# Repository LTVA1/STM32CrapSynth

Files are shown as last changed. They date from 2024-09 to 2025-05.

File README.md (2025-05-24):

# STM32CrapSynth

A software/hardware synth based on STM32F303RE, 4xAD9833 wave generators, one MM5437 noise generator and LTC1063 lowpass filter. Currently I seem to have burned the filter so instead there's 3rd PCM channel using the timer that was planned for filter clocking.

# Music demo

[Here's the demo](https://www.youtube.com/watch?v=L5HF_qdjZyU). I recorded each channel separately for channel oscilloscopes and then recorded them all for master sound which you can hear in the video.

# Folders

`board` - KiCAD project of the board that mounts on top of custom teacher's board like Arduino shield.
`pc_program` - small CLI program using serial library to send data to the MCU. There also lies `.fur` tracker module of the soundtrack (but remember that emulation is finished and it sounds off at times compared to real hardware)
`STM32CrapSynthFirmware` - MCU firmware written only with CMSIS register defs and simple functions. Zero HAL, LL, SPL libraries usage.

# Other programs

[STM32CrapSynth in Furnace](https://github.com/LTVA1/furnace/tree/stm32crapsynth) - A fork of Furnace chiptune tracker with added emulation of STM32CrapSynth. Also has an ability to export data (samples and stream of commands/wavetable data) into the file which is then used by `pc_program`.

# Overview and explanation

The device is capable of synthesizing 8 audio channels. Their signals are added together and the resulting sum is available on standard 3.5 mm audio jack.

There also are six phase reset timers. Two of them are MCU's internal timers and four other are four MCU's internal USARTs/UARTs which were made to generate a periodic interrupt (just like the usual timers). Each timer has 8-bit bitmask dictating which channels it affects. Each time timer fires the correspodning channel's signal phase is reset.

The device consists of three PCBs. I designed only the topmost PCB with `STM32CrapSynth` logo. Lower two PCBs were designed by my teacher.

Here is the overall image of the whole device.

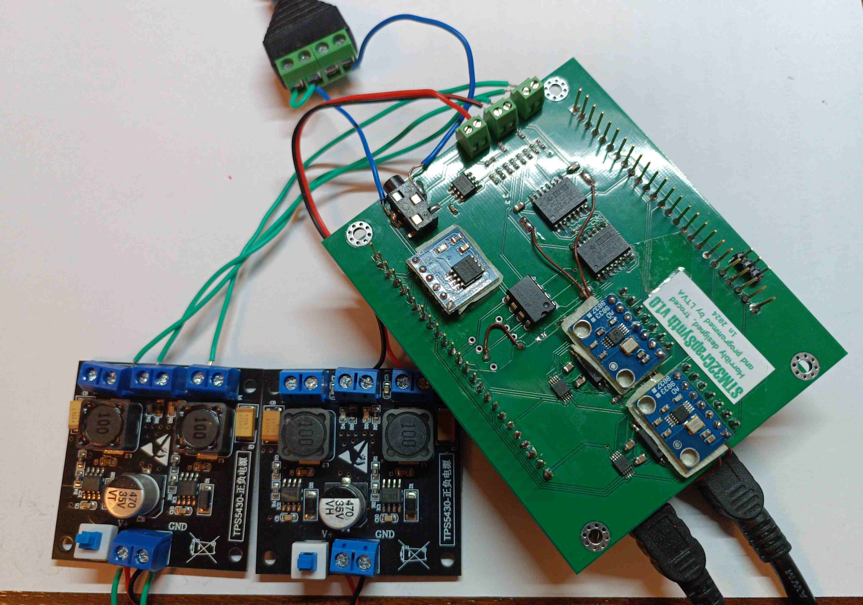
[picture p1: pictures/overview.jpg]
STM32CrapSynth


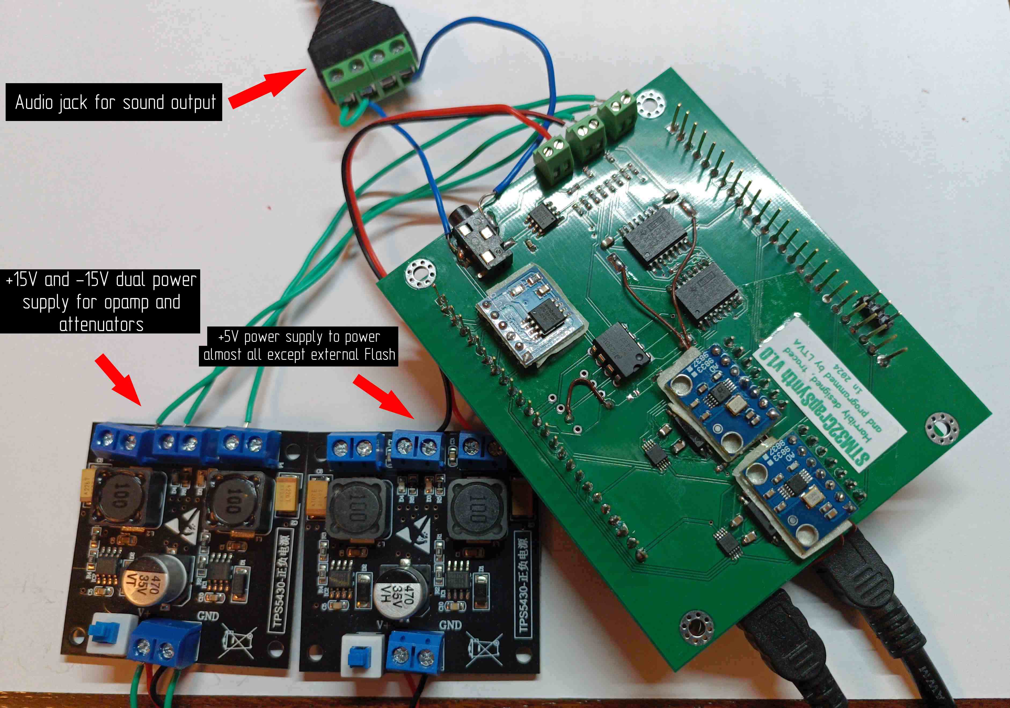
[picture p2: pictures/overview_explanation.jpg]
STM32CrapSynth explanation


## Top PCB

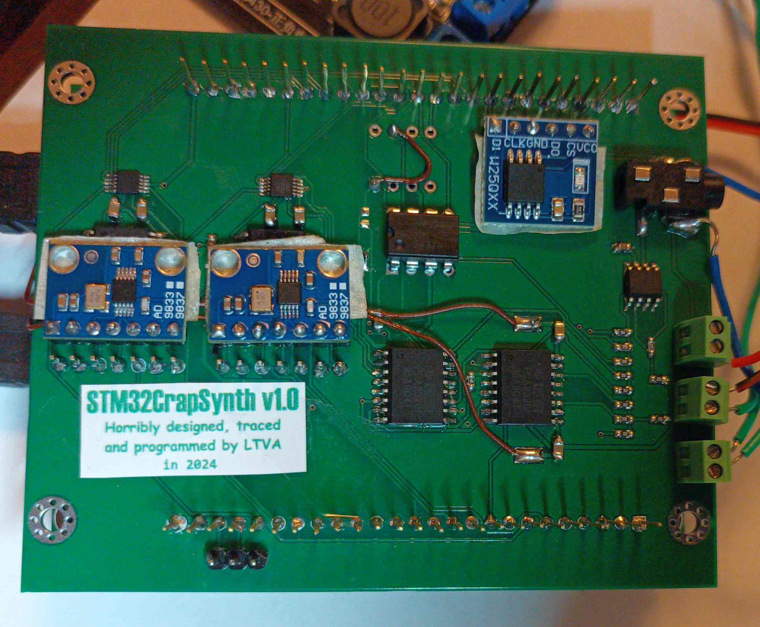
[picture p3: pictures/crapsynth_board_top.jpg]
Top PCB

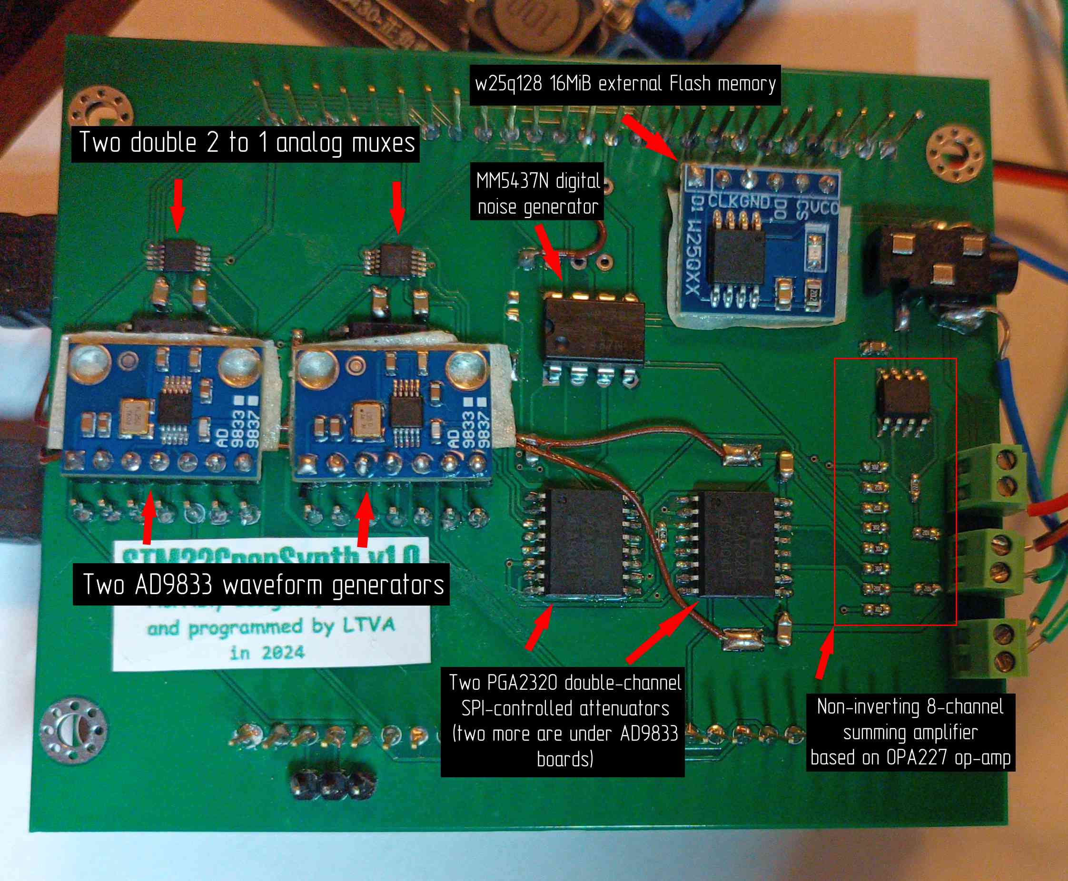
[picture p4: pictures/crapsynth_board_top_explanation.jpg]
Top PCB explanation


Muxes are used to connect either MCU timer's PWM signal or AD9833 signal to the attenuator's input. Four channels are formed, each having the ability to play sound from its own PWM timer or from its own AD9833 waveform generator.

Attenuators allow to control the channel's volume with 0.5dB step.

Noise generator can either be clocked from its own internal oscillator or from external signal (the latter is generated by dedicated MCU timer in PWM generation mode). With external clock and another control signal it's also possible to load LFSR directly from MCU, which allows to reset the noise generation at any time. That's how it is possible to "phase reset" noise channel.

The rightmost attenuator controls signals that come from brown wires. These are soldered to the outputs on MCU board that act as MCU's internal DACs outputs.

Eighth channel emerges from PWM signal that comes directly from MCU pin. Since op-amp isn't designed to handle such high frequencies, the form of the signal from this channel is distorted as you can see in demo video (triangle wave is "smoothed" on one side).

Wires were soldered to an external wires-to-audio-jack adapter because, when designing a PCB, I used wrong audio jack footprint.

External Flash memory holds a dump of commands. These commands control frequency, volume and other settings of each audio channel. They also specify the rate of their execution. Each time the timer fires (240 times a second in demo video) command execution happens until a special command is encountered. The special command stops any further execution until the timer fires next time.

## Middle PCB

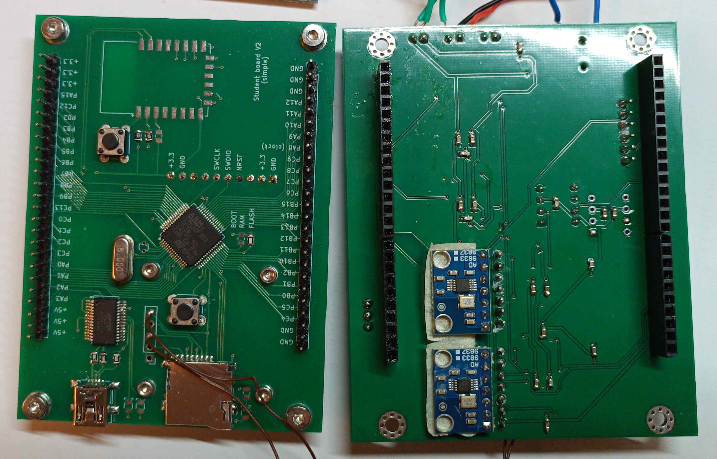
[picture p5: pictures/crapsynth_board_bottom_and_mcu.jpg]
Middle PCB

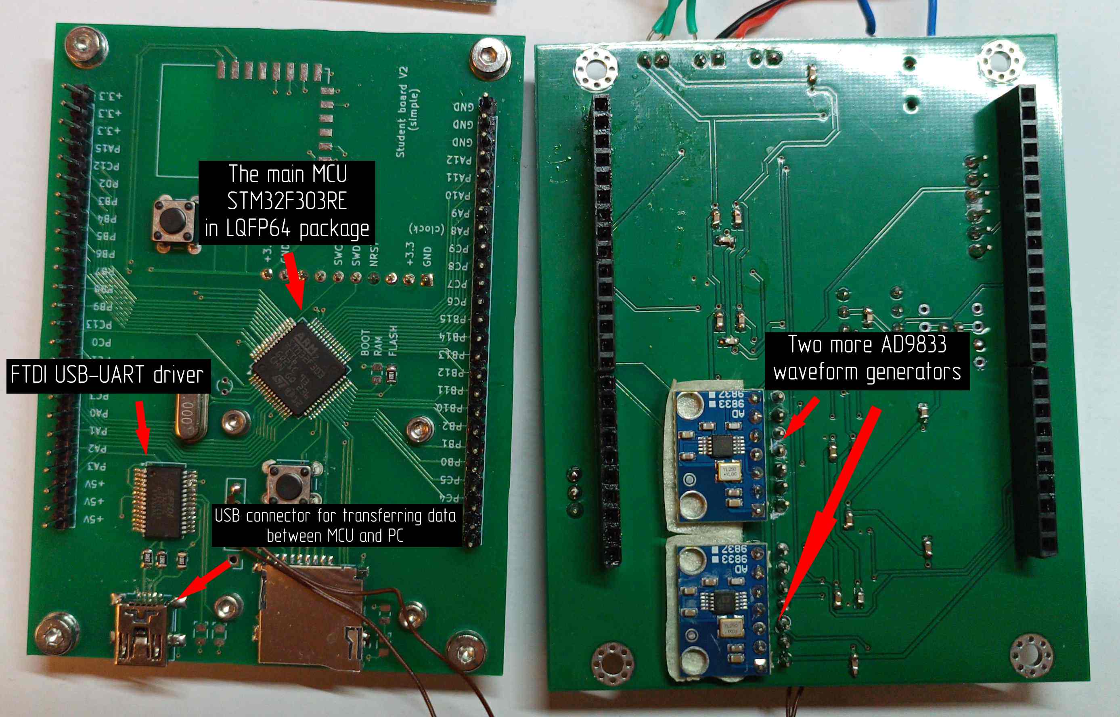
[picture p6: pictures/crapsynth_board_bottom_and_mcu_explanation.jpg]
Middle PCB explanation


On the other side on top PCB there are capacitors for power noise elimination and two more AD9833 boards.

On middle PCB you can see the main MCU that performs all the work and USB-UART bridge. The data transfer rate is 2MBaud. Also the places where DAC signal wires are soldered are visible.

## Bottom PCB

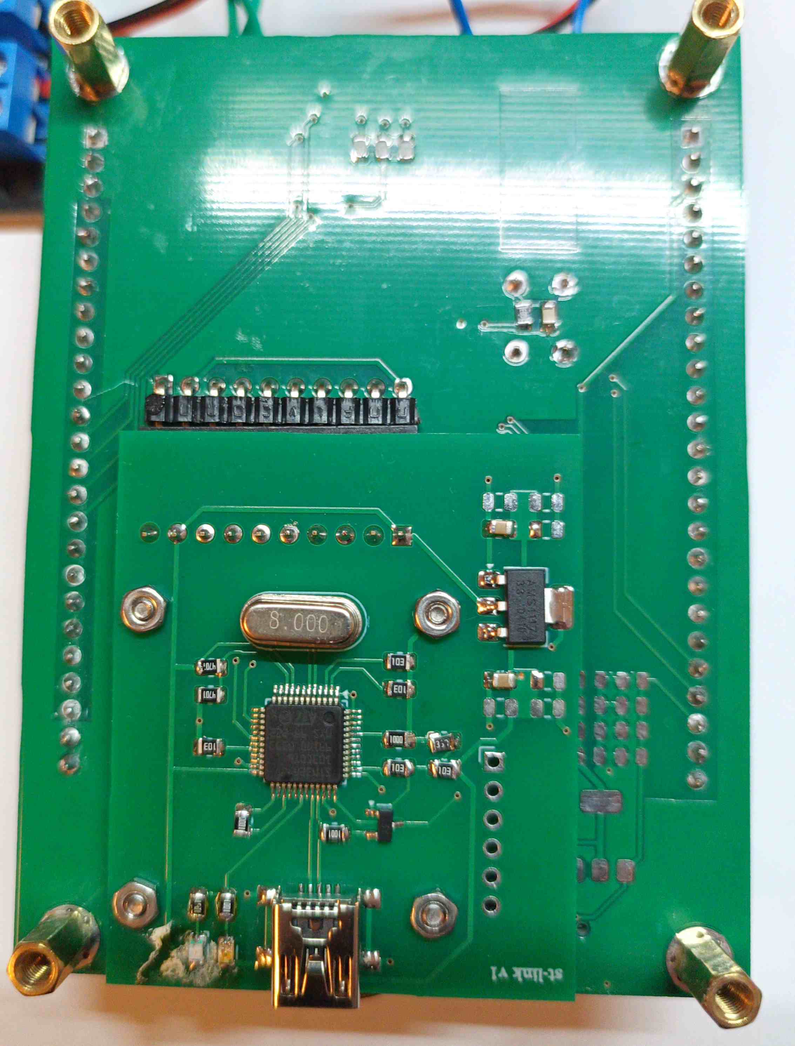
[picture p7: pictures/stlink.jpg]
Bottom PCB


Nothing special here, just a small PCB with custom STLink debugger design. A connector between bottom and middle PCB is visible on top. The USB connector provides power to STLink.

Also this board has 3.3V power regulator that supplies main MCU and external Flash memory.

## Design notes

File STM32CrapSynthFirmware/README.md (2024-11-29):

Startup file and linker script were modified. The correct size of CCMRAM (16KiB instead of 8KiB) was specified. CCMRAM sections for code and data were added in linker script. Startup file was modified to include CCMRAM copy of vector table, and copying routine was added to copy the part of the firmware from Flash to CCMRAM.

The main program copies interrupt vector table to CCMRAM and writes its new address to VTOR register of SCB.

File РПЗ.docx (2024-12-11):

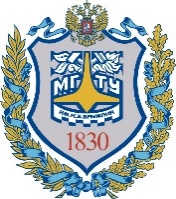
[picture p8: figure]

| Министерство науки и высшего образования Российской Федерации Федеральное государственное бюджетное образовательное учреждение высшего образования «Московский государственный технический университет имени Н.Э. Баумана (национальный исследовательский университет)» (МГТУ им. Н.Э. Баумана)

ФАКУЛЬТЕТ | «Радиоэлектроника и лазерная техника (РЛ)»
КАФЕДРА | «Технологии приборостроения (РЛ6)»

РАСЧЁТНО-ПОЯСНИТЕЛЬНАЯ ЗАПИСКА

К КУРСОВОЙ РАБОТЕ

НА ТЕМУ:

«Устройство программно-аппаратного синтеза звука»

ПО КУРСУ

«Цифровая электроника и микропроцессорная техника»

Студент | РЛ6-71 | | | | Г.С. Сарайкин
| (группа) | | (подпись, дата) | | (И.О. Фамилия)
Руководитель курсового проекта | | | | | Д. А. Семеренко
| | | (подпись, дата) | | (И.О. Фамилия)

2024 г.

# Введение

Аппаратный синтез звука с программным управлением может применяться в устройствах тестирования звуковой аппаратуры и синтезаторах.

Формирование сигнала возможно с помощью специализированных микросхем или использования аппаратных возможностей цифровых вычислительных устройств.

В курсовой работе реализован синтез методами DDS и ШИМ, также реализован сэмплерный синтез. Синтез реализован аппаратно с программным управлением, что позволяет достичь управления тембром и громкостью каналов во времени.

Цель работы — разработать устройство, генерирующее звук при помощи сэмплерного синтеза, а также методами DDS и ШИМ.

Назначение устройства — генерация восьми сигналов их суммирование и передача через звуковой разъём на устройство воспроизведения звука.

# 1. Обзор существующих решений

Стандартным методом формирования звуковых сигналов является использование ЦАПов с разнообразными устройствами, формирующими входящий в них поток цифровых данных.

Метод синтеза DDS (англ. Direct Digital Synthesis, прямой цифровой синтез звука) заключается в формировании сигнала при помощи преобразования цифрового значения фазы в цифровые значения мгновенной амплитуды по определённому закону. Фаза задаётся при помощи регистра аккумулятора фазы, к значению в котором с каждым тактом системной частоты прибавляется значение регистра, хранящего текущую настройку частоты. Благодаря тому, что регистр фазы переполняется (при сложении разряд переполнения отбрасывается), достигается циклическое нарастание значения фазы в регистре. Это позволяет синтезировать повторяющуюся во времени волну, установив закон соответствия выходной амплитуды текущему значению фазы [2]. Обобщённая функциональная схема DDS-генератора представлена на Рисунке 1.

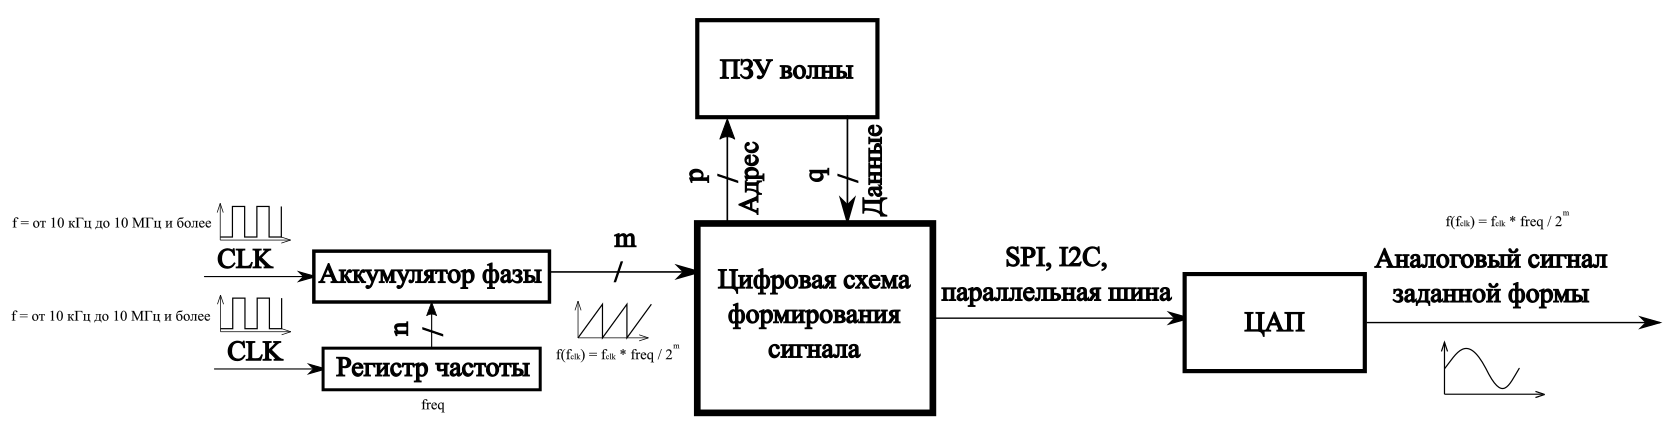
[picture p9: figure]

Рисунок 1 — Обобщённая функциональная схема DDS-генератора

Синтез ШИМ-сигнала при помощи таймера микроконтроллера заключается в создании выходного ШИМ-сигнала на основании текущих значений коэффициента заполнения и периода импульсов. Эти значения хранятся в регистрах таймера, реализованного внутри микроконтроллера. При изменении коэффициента заполнения меняется спектральный состав выходного сигнала. При частоте импульсов, попадающей в диапазон слышимости человека, изменение коэффициента заполнения воспринимается как изменение тембра звучания волны. Детальное объяснение применения ШИМ-сигнала для синтеза используемых в электронной музыке звуков см. в [3]. Обобщённая функциональная схема ШИМ-генератора представлена на Рисунке 2.

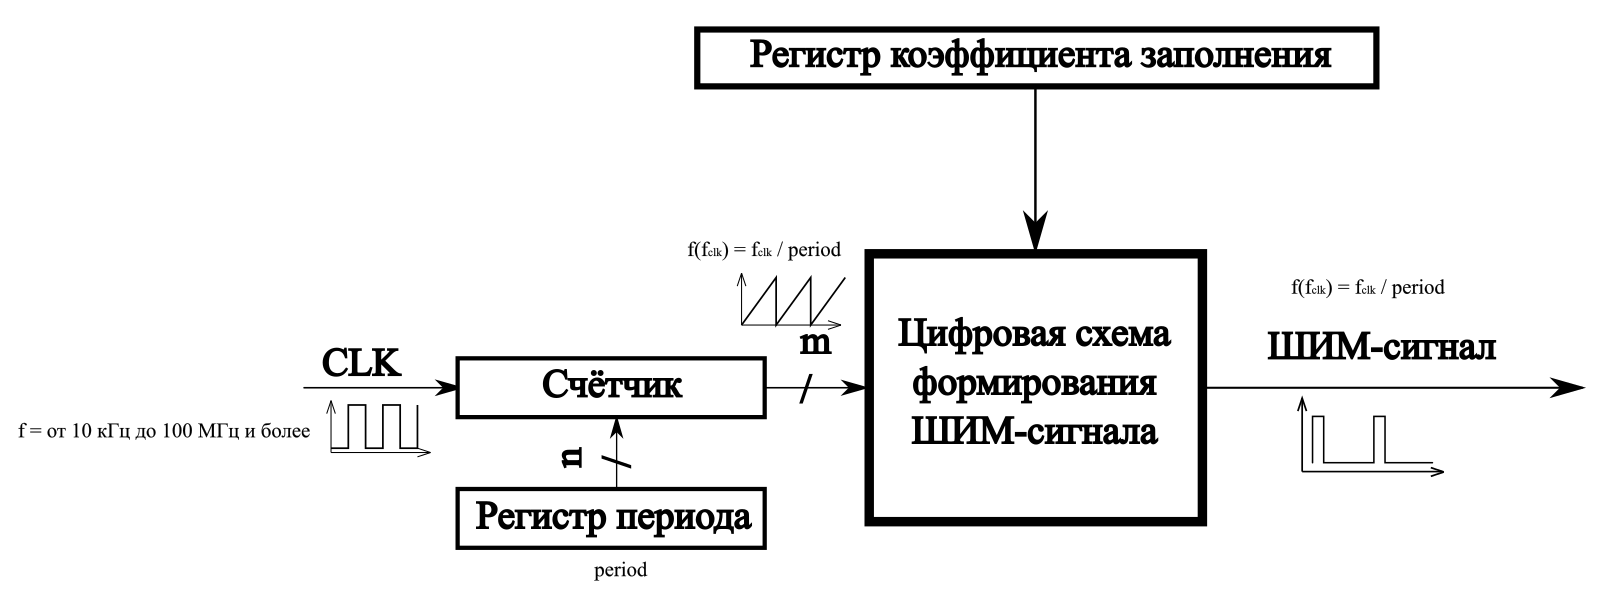
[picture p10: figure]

Рисунок 2 — Обобщённая функциональная схема синтезатора ШИМ-сигнала

Методы DDS и ШИМ схожи между собой, поскольку оба этих метода позволяют формировать повторяющийся во времени сигнал (один период волны). Метод ШИМ позволяет управлять тембром путём изменения коэффициента заполнения импульсов, а метод DDS — путём изменения типа синтезируемой волны (смены закона соответствия выходной амплитуды сигнала текущему значению фазы). Метод DDS в теории более универсален, поскольку позволяет выбирать между несколькими формами сигналов, в то время как метод ШИМ ограничен прямоугольной волной с изменяемым коэффициентом заполнения, что накладывает ограничения на тембры, которые возможно формировать при помощи этого метода. В некоторых устройствах можно встретить реализацию комбинации этих методов внутри одного функционального узла, т.е. доступна как генерация прямоугольных волн с изменяемым коэффициентом заполнения, так и других типов волн (треугольная и пилообразная) [6].

Сэмплерный синтез заключается в проигрывании подаваемых на вход ЦАПа наборов отсчётов оцифрованного звука, называемых сэмплами. Сэмпл можно воспроизвести целиком однократно, воспроизводить циклично целиком или проиграть часть сэмпла однократно, а оставшуюся часть циклично. Этот метод синтеза позволяет воспроизводить практически неограниченный набор звуков. Ограничениями метода являются глубина и частота дискретизации сэмплов и количество памяти, в которую записаны эти сэмплы [4].

Таблично-волновой синтез аналогичен сэмплерному синтезу за исключением того, что вместо сэмплов используются короткие наборы отсчётов (волновые таблицы), циклично воспроизводящиеся во времени. В результате получается волна, тембр которой можно менять, меняя эти наборы отсчётов [5].

Обобщённая функциональная схема сэмплерного/таблично-волнового синтезатора представлена на Рисунке 3.

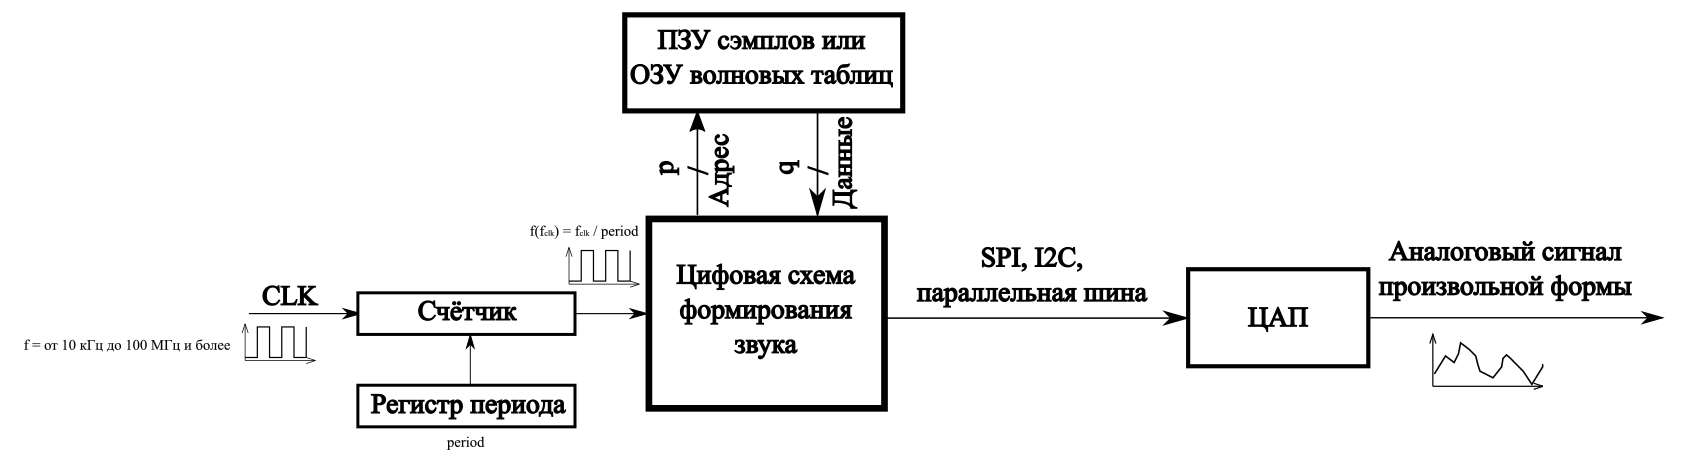
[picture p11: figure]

Рисунок 3 — Обобщённая функциональная схема сэмплерного/таблично-волнового синтезатора

Аналогами устройства являются звуковые чипы — специализированные микросхемы, основным назначением которых является генерация одного или нескольких сигналов, сумма которых в виде аналогового сигнала или потока цифровых данных подаётся на выход микросхемы.

Примером звукового чипа является MOS Technology SID [6]. Это микросхема трёхканального звукогенератора. Каждый канал может воспроизводить треугольную волну, шум, пилообразную волну или прямоугольную волну с настраиваемым коэффициентом заполнения. Частота волны каждого канала настраивается независимо. Для каждого канала реализована аппаратная ADSR-огибающая громкости. Сигнал каждого из каналов можно либо подключать напрямую на выход микросхемы, либо пропускать через аналоговый многорежимный фильтр с цифровым управлением. У фильтра настраиваются частота среза, добротность и режим (фильтр нижних частот, фильтр верхних частот, полосовой фильтр или любая комбинация этих режимов).

# 2. Алгоритм работы

Устройство генерирует звук с помощью внешних DDS-генераторов (синус, треугольная и квадратная волны), внутренних таймеров микроконтроллера (ШИМ, прямоугольная волна с изменяемым коэффициентом заполнения), внешнего генератора шума (псевдо-белый шум), внутренних таймеров микроконтроллера в связке с внутренними ЦАПами (волновые таблицы и сэмплы). Эти сигналы проходят через программно управляемые аттенюаторы, что позволяет задавать уровень и огибающую громкости. Сигнал одного из DDS-генераторов проходит через цифровой фильтр нижних частот пятого порядка с АЧХ Баттерворта. Частота среза фильтра зависит от частоты тактирования фильтра [7]. Ещё один ШИМ-сигнал приходит напрямую в аналоговый сумматор.

В устройстве также реализовано шесть таймеров сброса фазы. Для каждого таймера настраиваются каналы, на которые он воздействует. При каждом срабатывании таймера сбрасывается фаза всех каналов, на которые он воздействует. Описание принципа сброса фазы см. в описании соответствующих команд в Приложении А.

Функциональная схема устройства приведена на Рисунке 4.

Принципиальная электрическая схема устройства приведена в Приложении Г.

Рисунок 4 — Функциональная схема устройства

Сэмплы необходимо хранить во внутренней флэш-памяти микроконтроллера и во внутренней оперативной памяти. Волновые таблицы и последовательность команд, изменяющих параметры синтеза, необходимо хранить во внешней флэш-памяти, подключённой по SPI. Устройство использует 496 КиБ внутренней флэш-памяти микроконтроллера и 52 КиБ ОЗУ микроконтроллера для хранения сэмплов.

Программное управление осуществляется через интерфейс UART. ПК посылает команды, которые исполняются устройством. Команды позволяют запускать или останавливать исполнение потока команд, записанного во внешнюю флэш-память, а также позволяют загружать новые данные с ПК во внешнюю флэш-память, внутреннюю флэш-память и ОЗУ микроконтроллера.

Команды, хранящиеся во внешней флэш-памяти, состоят из байта, кодирующего тип команды и номер канала, параметры которого она меняет. После команды может следовать один или несколько байтов параметров команды, которые определяют новое значение параметра канала, к которому относится команда. Формат команд описан в Приложении А.

Обмен данными между микроконтроллером и внешней флэш-памятью осуществляется при помощи контроллера DMA по SPI.

Исполнение команд происходит через фиксированные интервалы времени, отсчитываемые одним из таймеров микроконтроллера (далее — таймер исполнения команд). Каждый раз, когда происходит срабатывание таймера, в обработчике прерывания таймера выставляется флаг запроса исполнения команд. В основном потоке программы проверяется установка флага, и при его установке начинается исполнение команд. По окончании исполнения команд флаг сбрасывается.

Данные с ПК передаются при помощи специально разработанной программы с интерфейсом командной строки. Программа читает файл, название которого задаётся пользователем. В файле записана последовательность команд и сэмплы. Программа формирует команды с пакетами данных, передаваемые микроконтроллеру, и ожидает подтверждения приёма от микроконтроллера. Пакеты данных содержат информацию, прочитанную программой из файла. Формат пакетов, которыми обмениваются микроконтроллер и программа, приведён в Приложении Б. В консоль выводится информация о прогрессе передачи данных, обновляемая с каждой передачей пакета. После передачи всех данных пользователю предоставляется возможность запускать или останавливать исполнение потока команд.

Формат файла приведён в Приложении В.

# Заключение

В курсовой работе разработано устройство многоканальной генерации звука, реализовано управление устройством с ПК.

Продемонстрирована возможность выполнения потока команд, записанного во внешнюю флэш-память, а также использование DDS-генераторов и внутренних таймеров микроконтроллера для генерации сигналов на частотах от 10 Гц до 20 кГц. Устройство способно выполнять обновление параметров каналов с частотой до 240 Гц.

Устройство можно улучшить путём увеличения числа каналов и/или увеличения возможностей каналов. Вместо использования отдельных микросхем DDS-генераторов и генератора шума возможна реализация синтеза на ПЛИС. При подключении к ПЛИС внешней оперативной памяти станет возможно увеличение общего объёма памяти сэмплов, а также реализация самих каналов сэмплов на ПЛИС, что потребует использования внешних ЦАПов.

Исходный код программы для микроконтроллера доступен по ссылке [8]. Исходный код программы для ПК доступен по ссылке [9].

# Приложение А. Формат команд управления параметрами синтеза

Команды делятся на обычные и служебные. Обычные команды предназначены для изменения одного из параметров синтеза определённого канала, в то время как служебные команды контролируют порядок выполнения обычных команд. Общий формат команд представлен в Таблице А1.

Таблица А1

Байт 1 | Байты 2, 3, …
Байт команды | Параметр(-ы) (размер и наличие зависят от команды)

Формат обычных команд для каналов DDS/ШИМ представлен в Таблице А2. Формат обычных команд для канала шума представлен в Таблице А3. Формат команд для каналов сэмплов представлен в Таблице А4. Формат команд для каналов таймеров сброса фазы представлен в Таблице А5. Формат служебных команд представлен в Таблице А6.

Нумерация каналов начинается с нуля. Соответственно, для DDS/ШИМ каналов номер лежит в диапазоне от 0 до 3. Для каналов ЦАПов номер лежит в диапазоне от 0 до 2, где последний канал соответствует ЦАПу, реализованному при помощи ШИМ. Для каналов таймеров сброса фазы номер лежит в диапазоне от 0 до 5.

Каждый байт параметра представляется в виде двух латинских букв, написанных слитно, например, aa. Если параметр имеет размер более одного байта, он представляется в виде нескольких групп из двух латинских букв, например, aa aa. В таком случае сначала следует младший байт, а потом старший. Такой порядок байтов сохраняется и при большем размере параметра (3 и более байтов), в этом случае сначала идёт самый младший байт, потом следующий за ним, и так далее до самого старшего байта. В случае наличия нескольких параметров каждый параметр обозначается своими буквами. Например, aa aa bb значит, что сначала следует один параметр размером два байта, а после него следует второй параметр размером один байт.

Если количество битов параметра не кратно восьми (например, написано, что значение параметра занимает 14 бит, а сам параметр занимает два байта, т.е. 16 бит), то используются только младшие биты (в описанном случае используются 14 младших бит, два старших бита не используются и игнорируются при исполнении команды).

Если указано использование конкретных значений параметра, например, описаны значения от 0 до 5, то значения параметра, не попадающие в диапазон, не приводят к какому-либо изменению параметров синтеза. При этом выполнение команд не прерывается.

Если информации о параметре не указано, то параметр отсутствует, и команда занимает один байт.

Таблица А2

Описание команды | Значение байта команды, n — номер канала | Формат параметра(-ов) | Описание функций команды и параметра(-ов)
Установка громкости | 8×n | vv | vv — громкость канала. Если vv = 0, то громкость равна нулю, иначе громкость равна -97+0,5× (vv)дБ для типов волн 1 и 2 и -88+0,5× (vv)дБ для типов волн 3 и 4.
Установка типа волны | 8×n+1 | ww | ww — тип волны, синтезируемой каналом: 0 — нет сигнала; 1 — синус; 2 — треугольная волна; 3 — квадратная волна; 4 — квадратная волна с удвоенной частотой; 5 — прямоугольная волна с настраиваемым коэффициентом заполнения.
Частота для типов волн от 1 до 4 | 8×n+2 | ff ff ff ff | ff ff ff ff — 28-битное целое положительное число, задающее частоту сигнала по формуле f_(signal) =((ff ff ff ff)×25 МГц)/(2^28) . Максимальная частота составляет 12,5 МГц для типа волны 1 и 2 МГц для остальных типов.
Сброс фазы | 8×n+3 | | При исполнении этой команды фаза волны принудительно устанавливается равной нулю вне зависимости от типа волны и текущих значений частоты и фазы.
Частота для типа волны 5 | 8×n+4 | pp aa aa | pp — предделитель частоты, aa aa — делитель частоты. Частота сигнала вычисляется по формуле f_(signal) =(72 МГц)/(((aa aa) + 1)×((pp)+1)) .
Коэффициент заполнения для типа волны 5 | 8×n+5 | dd dd | dd dd — коэффициент заполнения. Реальный коэффициент заполнения вычисляется по формуле d_(real) =((dd dd))/((aa aa))×100% , где aa aa — текущее значение делителя частоты (см. описание предыдущей команды).
Включение изменения громкости по пересечению нуля | 8×n+6 | | Команда применяется к паре каналов (пары каналов: 0 и 1, 2 и 3) одновременно при исполнении команды для одного из этих каналов
Выключение изменения громкости по пересечению нуля | 8×n+7 | | Команда применяется к паре каналов (пары каналов: 0 и 1, 2 и 3) одновременно при исполнении команды для одного из этих каналов

Таблица А3

Описание команды | Значение байта команды | Формат параметра(-ов) | Описание функций команды и параметра(-ов)
Установка громкости | 32 | vv | vv — громкость канала. Если vv = 0, то громкость равна нулю, иначе громкость равна -88+0,5× (vv) дБ.
Тактирование генератора шума от внутреннего источника | 33 | | Частота тактирования составляет примерно 100 кГц
Тактирование генератора шума от внешнего источника | 34 | | Частота тактирования настраивается командой «Частота внешнего тактирования»
Включение изменения громкости по пересечению нуля | 35
Выключение изменения громкости по пересечению нуля | 36
Частота внешнего тактирования | 37 | pp aa aa | pp — предделитель частоты, aa aa — делитель частоты. Частота тактирования генератора шума вычисляется по формуле f_(clk) =(72 МГц)/(((aa aa) + 1)×((pp)+1)) . Частота тактирования не должна превышать 300 кГц.
Сброс фазы | 38 | | Команда загружает в РСЛОС генератора шума значение, заданное командой «Установка начального состояния РСЛОС»
Установка начального состояния РСЛОС | 39 | ll ll ll | ll ll ll — 23-битное значение состояния РСЛОС

Таблица А4

Описание команды | Значение байта команды, n — номер канала | Формат параметра(-ов) | Описание функций команды и параметра(-ов)
Установить громкость канала | 40+16×n | vv | vv — громкость канала. Если vv = 0, то громкость равна нулю, иначе громкость равна -88+0,5× ( vv ) дБ для n∈{0,1} и -12+10×log_10 ((256+3×(vv))/256) дБ для n=2.
Начать воспроизведение сэмпла | 41+16×n | | Сэмпл начинает воспроизводиться с заданными ранее начальными параметрами (см. следующие команды)
Начать воспроизведение сэмпла с зацикливанием | 42+16×n | | Сэмпл начинает воспроизводиться с заданными ранее начальными параметрами (см. следующие команды). При этом учитывается настройка точки зацикливания
Начать воспроизведение волновой таблицы | 43+16×n | | Волновая таблица начинает воспроизводиться с заданными ранее начальными параметрами (см. следующие команды)
Остановить воспроизведение волновой таблицы или сэмпла | 44+16×n
Задать стартовый адрес сэмпла во внутренней флэш-памяти | 45+16×n | ss ss ss | ss ss ss — сдвиг начала сэмпла относительно начала области внутренней флэш-памяти, отведённой под сэмплы
Задать стартовый адрес сэмпла в ОЗУ | 46+16×n | ss ss | ss ss — сдвиг начала сэмпла относительно начала области ОЗУ, отведённой под сэмплы
Сброс фазы волновой таблицы или сэмпла | 47+16×n | | В случае волновой таблицы фаза волны, представленной в ней, сбрасывается в ноль. В случае сэмпла воспроизведение сэмпла начинается заново с первого отсчёта этого сэмпла.
Частота воспроизведения сэмпла или волновой таблицы | 48+16×n | pp aa aa | pp — предделитель частоты, aa aa — делитель частоты. Частота тактирования воспроизведения сэмпла вычисляется по формуле f_(sample) =(72 МГц)/(((aa aa) + 1)×((pp)+1)) . Частота воспроизведения волновой таблицы в 256 раз меньше f_(sample) .
Включение изменения громкости по пересечению нуля | 49+16×n | | Команда применяется к паре каналов (пара каналов: 0 и 1) одновременно при исполнении команды для одного из этих каналов
Выключение изменения громкости по пересечению нуля | 50+16×n | | Команда применяется к паре каналов (пара каналов: 0 и 1) одновременно при исполнении команды для одного из этих каналов
Задать адрес точки зацикливания сэмпла во внутренней флэш-памяти | 51+16×n | ll ll ll | ll ll ll — сдвиг точки зацикливания относительно стартового адреса сэмпла во флэш-памяти
Задать адрес точки зацикливания сэмпла в ОЗУ | 52+16×n | ll ll | ll ll — сдвиг точки зацикливания относительно стартового адреса сэмпла в ОЗУ
Задать длину сэмпла во внутренней флэш-памяти | 53+16×n | ll ll ll | ll ll ll — длина сэмпла во флэш-памяти
Задать длину сэмпла в ОЗУ | 54+16×n | ll ll | ll ll — длина сэмпла в ОЗУ

Задать тип волны

55+16×n

ww

ww — тип волны, синтезируемой каналом:

0 — нет сигнала;

1 — волновая таблица или сэмпл;

2 — треугольная волна;

3 — сумма волновой таблицы или сэмпла и треугольной волны;

4 — шум;

5 — сумма волновой таблицы или сэмпла и шума;

6 — прямоугольная волна с настраиваемым коэффициентом заполнения (при помощи формирования волновой таблицы);

7 — пилообразная волна (при помощи формирования волновой таблицы). При использовании типов волн 3 и 5 возможно переполнение итогового значения, в этом случае отсчёты итогового сигнала вычисляются по модулю 4096. Для n=2 синтезируются только волны 0, 1, 6, 7. Остальные каналы могут синтезировать все волны.
Коэффициент заполнения для типа волны 6 | 56+16×n | dd | dd — коэффициент заполнения. Реальный коэффициент заполнения вычисляется по формуле d_(real) =((dd))/256×100%.
Данные волновой таблицы | 57+16×n | [dd] | [dd] — массив из 256 байтов, задающий волновую таблицу. Каждый байт соответствует одному отсчёту волновой таблицы. Массив данных в неизменном виде используется в качестве волновой таблицы.
Амплитуда треугольной волны или шума | 58+16×n | aa | aa — амплитуда треугольной волны или шума, находится в диапазоне от 0 до 11. Амплитуда вычисляется по формуле A_(wave) =(2^((aa+1)))/4096×A_(max) , где A_(max) — максимально возможная для ЦАПа амплитуда выходного сигнала.

Примечание: частота треугольной волны вычисляется по формуле f_(triangle) =(2^((12-(aa+1))))/8192×f_(sample) , где f_(sample) — частота воспроизведения сэмпла или волновой таблицы, aa — текущее значение амплитуды (см. описание команды «Амплитуда треугольной волны или шума»).

Таблица А5

Описание команды | Значение байта команды, n — номер канала | Формат параметра(-ов) | Описание функций команды и параметра(-ов)
Установить битовую маску таймера | 136+8×n | bb | bb — битовая маска воздействия таймеров на каналы. Если бит равен единице, то таймер воздействует на канал и сбрасывает его фазу. Если бит равен нулю, то воздействия на канал не происходит. Соответствие битов и каналов (от младшего бита к старшим): биты 0-3 — каналы 0-3 DDS/ШИМ, бит 4 — канал шума, биты 5-7 — каналы 0-2 ЦАПов.
Частота срабатывания таймера 1 | 137+8×n | pp aa aa | pp — предделитель частоты, aa aa — делитель частоты. Частота срабатывания таймера вычисляется по формуле f_(timer) =(72 МГц)/(((aa aa) + 1)×((pp)+1)) . Работает только для n=0 .
Сброс фазы таймера | 138+8×n
Включить таймер | 139+8×n
Выключить таймер | 140+8×n
Частота срабатывания таймера 2 | 141+8×n | aa aa aa | aa aa aa — делитель частоты. Частота срабатывания таймера вычисляется по формуле f_(timer) =(72 МГц)/(((aa aa aa) + 1)) . Работает только для n=1 .
Частота срабатывания таймеров 3-6 | 142+8×n | ff ff | ff ff — делитель частоты. Значение делителя не должно превышать 65527. Частота срабатывания таймера вычисляется по формуле f_(timer) =(7,2 МГц)/((ff ff ff)) для n=2 и по формуле f_(timer) =(3,6 МГц)/((ff ff ff)) для n∈{3,4,5} . Работает только для n∈{2,3, 4,5} .

Таблица А6

Описание команды | Значение байта команды | Формат параметра(-ов) | Описание функций команды и параметра(-ов)
Ждать до следующего срабатывания таймера исполнения команд | 251
Установить частоту срабатывания таймера исполнения команд | 252 | aa aa aa aa | aa aa aa aa — делитель частоты. Частота срабатывания таймера вычисляется по формуле f_(tick) =(72 МГц)/((aa aa aa aa) + 1) .
Установить точку зацикливания | 253 | aa aa aa aa | aa aa aa aa — абсолютный адрес во внешней флэш-памяти. При исполнении команды прерывается исполнение потока команд. Микроконтроллер переходит на этот адрес и начинает читать и исполнять команды.
Остановить исполнение команд | 254
Ничего не делать | 255 | | Микроконтроллер не изменяет никаких параметров синтеза и переходит к исполнению следующей команды.

# Приложение Б. Формат пакетов обмена данными между микроконтроллером и ПК

Пакеты делятся на пакеты данных, передаваемые от ПК микроконтроллеру, и ответные пакеты, отправляемые микроконтроллером ПК.

Общий формат команд, передаваемых от ПК микроконтроллеру, представлен в Таблице Б1. Нумерация байтов начинается с единицы.

Числа, представление которых занимает несколько байтов, записаны младшим байтом вперёд, если не указано иное.

Таблица Б1

Номер байта (или диапазон для группы байтов) | Размер (указывается для группы байтов) | Описание байта (группы байтов)
1 | | Байт синхронизации, всегда равен 6916
2-3 | 2 | Размер пакета минус один байт. Сначала идёт старший байт, а потом младший.
4 | | Код команды
4-(4 + размер - 8) | размер - 8 | Данные. Эта часть пакета может отсутствовать.
(4 + размер - 7) | | Проверочный байт, вычисляется как исключающее ИЛИ от всех предыдущих байтов

Общий формат команд, передаваемых от микроконтроллера ПК, представлен в Таблице Б2. Нумерация байтов начинается с единицы.

Таблица Б2

Номер байта (или диапазон для группы байтов) | Размер (указывается для группы байтов) | Описание байта (группы байтов)
1 | | Байт синхронизации, всегда равен 6916
2 | | Код пакета
3 | 45 | Данные пакета
48 | | Проверочный байт, вычисляется как исключающее ИЛИ от всех предыдущих байтов

Коды команд, передаваемых от ПК микроконтроллеру, представлены в Таблице Б3.

Таблица Б3

Код команды | Описание команды
0 | Загрузить данные пакета во внутреннюю флэш-память
1 | Загрузить данные пакета во внутреннее ОЗУ
2 | Загрузить данные пакета во внешнюю флэш-память
3 | Начать исполнение потока команд
4 | Закончить исполнение потока команд

Коды пакетов, передаваемых от микроконтроллера ПК, представлены в Таблице Б4.

Таблица Б4

Код пакета | Описание пакета
0 | Начальный пакет: версия программы микроконтроллера, количество свободной памяти, размер внешней флэш-памяти и т.д.
1 | Пакет с информацией о завершении записи данных во внутреннюю флэш-память
2 | Пакет с информацией о завершении записи данных во внутреннее ОЗУ
3 | Пакет с информацией о завершении записи данных во внешнюю флэш-память
4 | Пакет с сообщением о неправильном значении проверочного байта
5 | Пакет с сообщением о неизвестном коде принятой команды

Команды, передаваемые от ПК микроконтроллеру и имеющие коды от 0 до 2, имеют общий формат данных. Формат представлен в Таблице Б5.

Таблица Б5

Номер байта (или диапазон для группы байтов) | Размер (указывается для группы байтов) | Описание байта (группы байтов)
1-4 | 4 | 32-битное положительное число, начальное смещение данных пакета относительно начала области памяти, в которую он записывается.
5-конец | (размер блока - 4) | Данные, которые записываются в соответствующую память

Команды, передаваемые от ПК микроконтроллеру и имеющие коды от 3 до 4, не имеют блока данных. Таким образом, их общая длина составляет 5 байтов, а в поле размера указывается число 4.

Формат данных пакета, передаваемого от микроконтроллера ПК и имеющего код пакета 0, представлен в Таблице Б6.

Таблица Б6

Номер байта (или диапазон для группы байтов) | Размер (указывается для группы байтов) | Описание байта (группы байтов)
1-4 | 4 | 32-битное положительное число, размер программы микроконтроллера, занимаемый ею во внутренней флэш-памяти
5-8 | 4 | 32-битное положительное число, начальное смещение области памяти, отведённой под сэмплы, во внутренней флэш-памяти микроконтроллера
9-12 | 4 | 32-битное положительное число, начальное смещение области памяти, отведённой под сэмплы, в ОЗУ микроконтроллера
13-16 | 4 | 32-битное положительное число, максимальная поддерживаемая программой микроконтроллера версия файла (см. Приложение В)
17-20 | 4 | 32-битное положительное число, версия программы микроконтроллера
21-24 | 4 | 32-битное положительное число, размер (в байтах) внешней флэш-памяти
25-32 | 8 | 64-битное положительное число, UID внешней флэш-памяти
33 | 1 | Идентификатор производителя внешней флэш-памяти
34-45 | 12 | Байты не используются. Игнорировать при чтении.

Команды, передаваемые от микроконтроллера ПК и имеющие коды от 1 до 3, имеют общий формат данных. Формат представлен в Таблице Б5.

Таблица Б6

Номер байта (или диапазон для группы байтов) | Размер (указывается для группы байтов) | Описание байта (группы байтов)
1 | | Проверочный байт пришедшего от ПК пакета данных
2-5 | 4 | 32-битное положительное число, начальное смещение данных в пришедшем от ПК пакете данных
6-7 | 2 | 16-битное положительное число, длина блока данных в пришедшем от ПК пакете данных
8-45 | 38 | Байты не используются. Игнорировать при чтении.

Пакеты, передаваемые от микроконтроллера ПК и имеющие коды от 4 до 5, не содержат полезной информации в блоке данных. Поэтому при чтении все 45 байтов блока данных игнорируются.

# Приложение В. Формат файла данных синтеза

Файл формируется модифицированной версией программы Furnace Tracker. В программу добавлена поддержка устройства: эмуляция генерации звука, возможность написания музыки для устройства и экспорт данных в файл [10].

Файл разбит на блоки и имеет бинарный формат. Все блоки следуют друг за другом в порядке, указанном в Таблице В1, без разделителей. Общий формат файла представлен в Таблице В1.

Поля данных, представляющие числа и занимающие более одного байта, записаны младшим байтом вперёд.

Таблица В1

Название блока | Описание блока
Заголовок | Идентификатор файла, версия формата, общий размер файла
Блок сэмплов флэш-памяти | Данные сэмплов, которые располагаются во внутренней флэш-памяти микроконтроллера
Блок сэмплов ОЗУ | Данные сэмплов, которые располагаются в ОЗУ микроконтроллера
Блок потока команд | Последовательность команд изменения параметров синтеза

Формат заголовка файла представлен в Таблице В2.

Таблица В2

Смещение от начала файла в байтах | Формат данных | Размер данных в байтах | Описание данных
0 | ASCII-строка | 4 | Идентификатор формата файла: «CRAP».
4 | 32-битное целое положительное число | 4 | Версия файла
8 | 32-битное целое положительное число | 4 | Размер файла

Формат блока сэмплов флэш-памяти представлен в Таблице В3.

Таблица В3

Смещение от начала блока в байтах | Формат данных | Размер данных в байтах | Описание данных
0 | ASCII-строка | 13 | Идентификатор блока: «FLASH SAMPLES».
13 | 32-битное целое положительное число | 4 | Размер данных (dsize)
17 | Массив байтов | dsize | Данные сэмплов. Один непрерывный блок, который без изменений загружается во флэш-память микроконтроллера по адресу начального смещения блока

Формат блока сэмплов ОЗУ представлен в Таблице В4.

Таблица В4

Смещение от начала блока в байтах | Формат данных | Размер данных в байтах | Описание данных
0 | ASCII-строка | 11 | Идентификатор блока: «RAM SAMPLES»
11 | 32-битное целое положительное число | 4 | Размер данных (dsize)
15 | Массив байтов | dsize | Данные сэмплов. Один непрерывный блок, который без изменений загружается в ОЗУ микроконтроллера по адресу начального смещения блока

Формат блока потока команд представлен в Таблице В5.

Таблица В5

Смещение от начала блока в байтах | Формат данных | Размер данных в байтах | Описание данных
0 | ASCII-строка | 14 | Идентификатор блока: «REGISTERS DUMP»
14 | 32-битное целое положительное число | 4 | Размер данных (dsize)
18 | Массив байтов | dsize | Поток команд. Один непрерывный блок, который без изменений загружается микроконтроллером во внешнюю флэш-память, начиная с нулевого адреса

Примечание: в начале потока команд первые четыре байта задают начальное значение делителя частоты для таймера исполнения команд. Следом идёт первая команда «Ждать до следующего срабатывания таймера исполнения команд», после которой следуют остальные команды.

# Приложение Г. Принципиальная электрическая схема устройства

Принципиальная электрическая схема устройства приведена на Рисунках Г.1—Г.7.

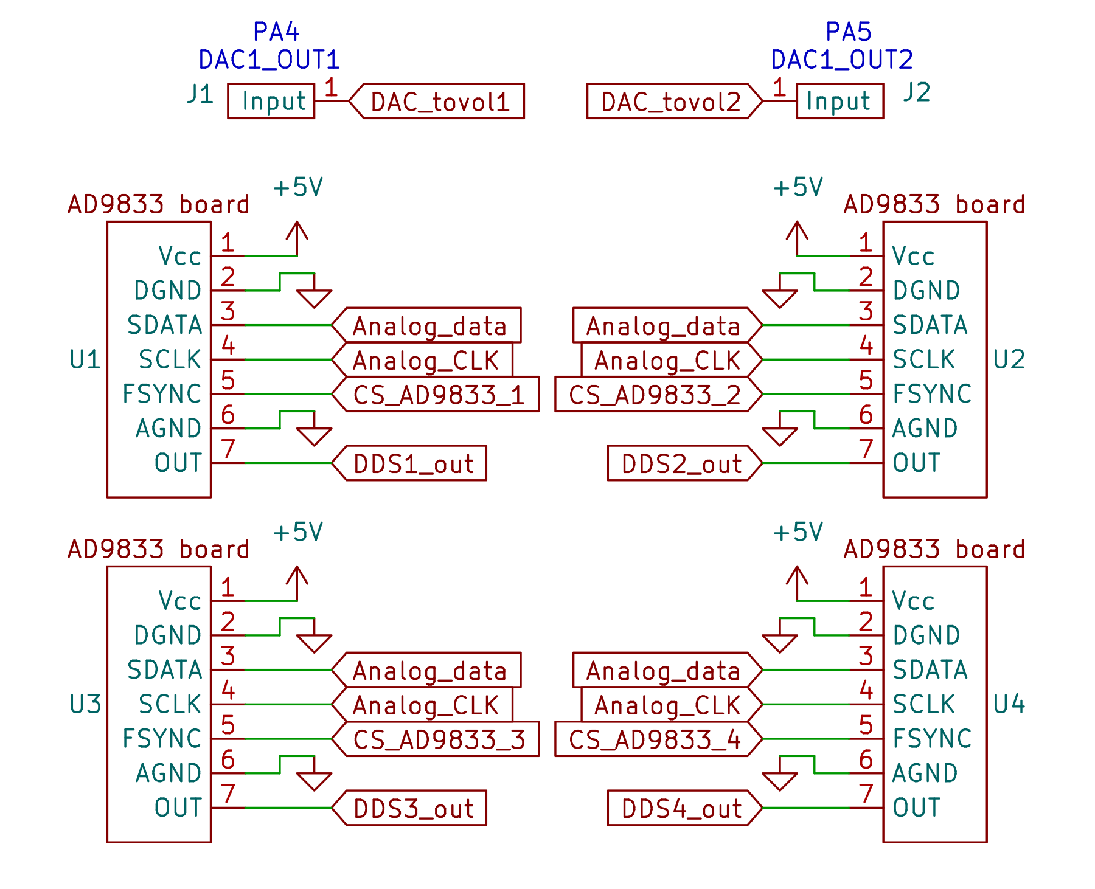
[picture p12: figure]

Рисунок Г.1 — Электрическая принципиальная схема устройства. DDS-генераторы и сигналы с ЦАПов микроконтроллера.

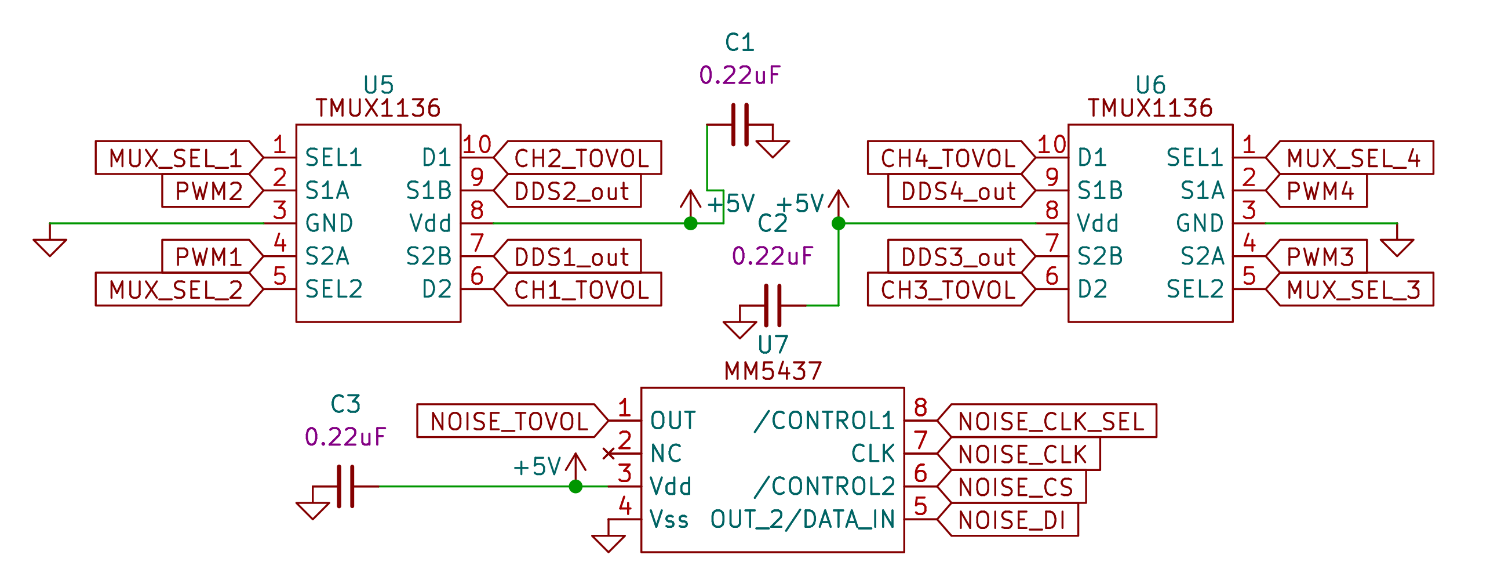
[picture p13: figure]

Рисунок Г.2 — Электрическая принципиальная схема устройства. Мультиплексоры сигналов каналов DDS/ШИМ и генератор шума.

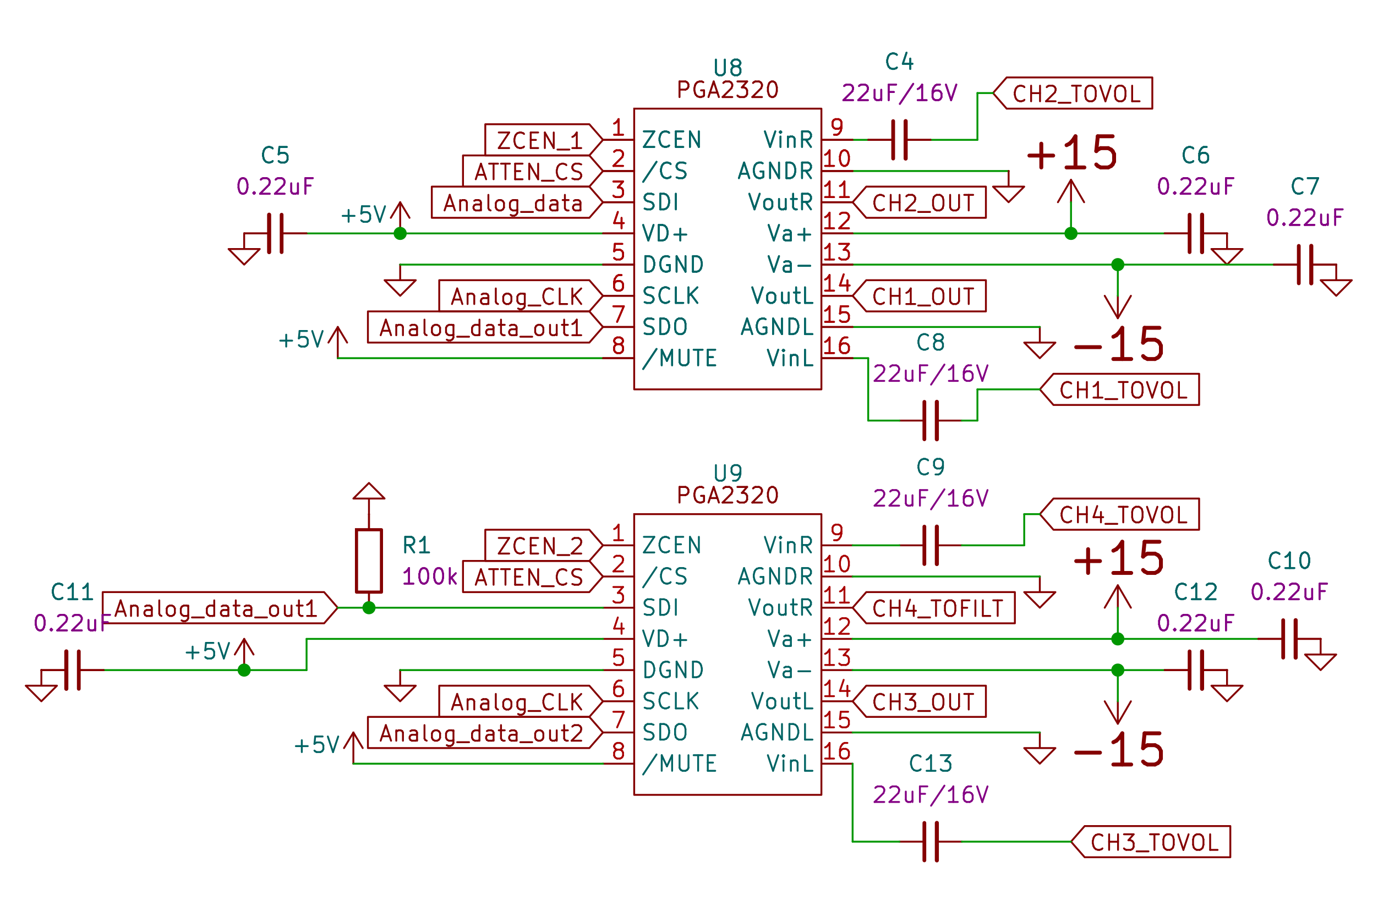
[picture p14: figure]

Рисунок Г.3 — Электрическая принципиальная схема устройства. Программно управляемые аттенюаторы четырёх каналов DDS/ШИМ.

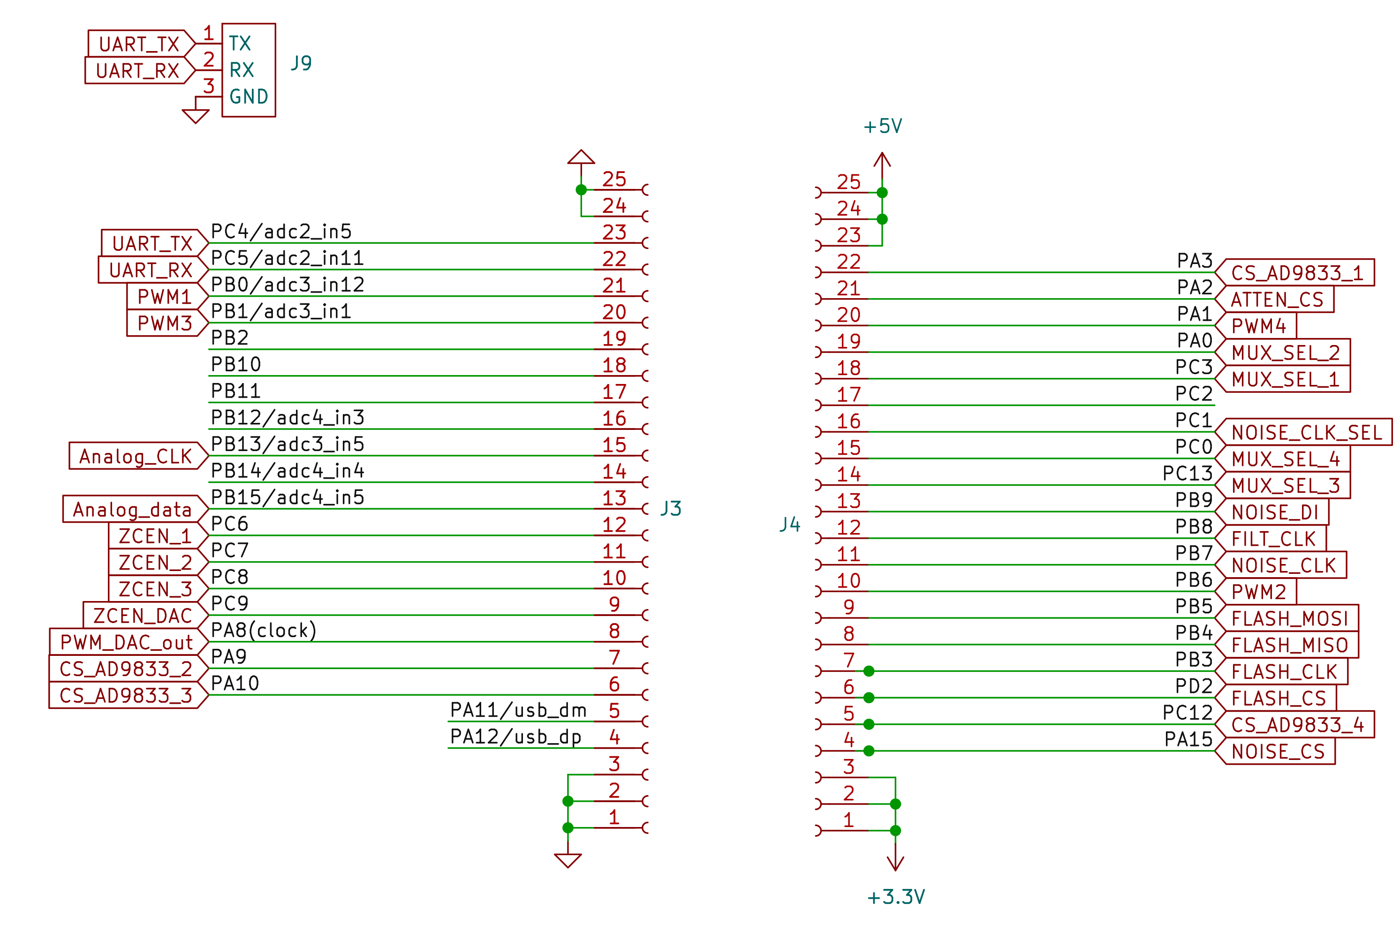
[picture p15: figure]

Рисунок Г.4 — Электрическая принципиальная схема устройства. Разъёмы подключения к плате с микроконтроллером и разъём подключения адаптера USB-UART.

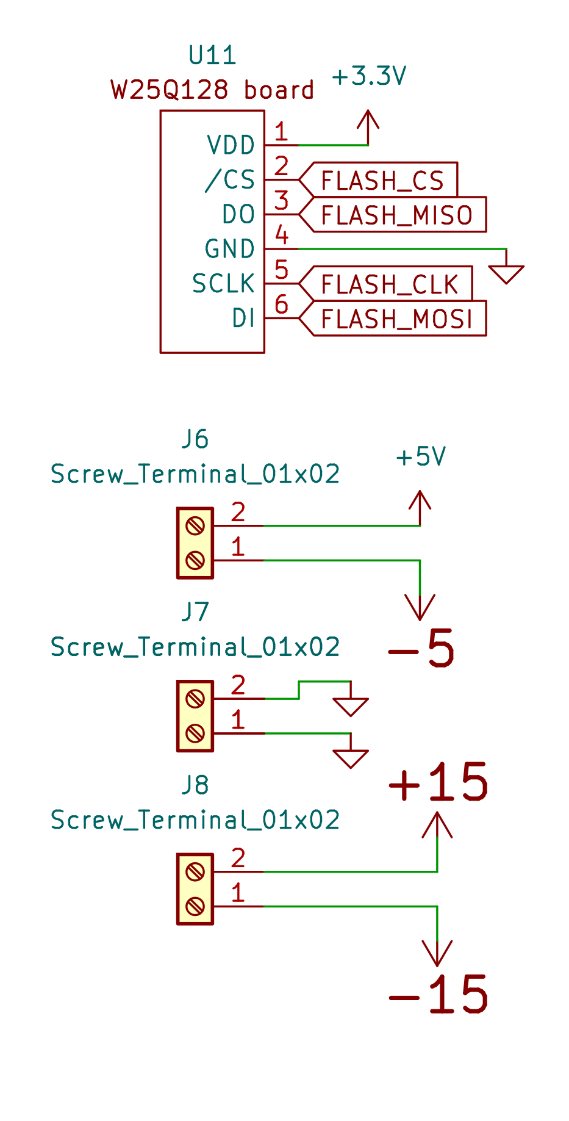
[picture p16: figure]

Рисунок Г.5 — Электрическая принципиальная схема устройства. Разъёмы подключения питания и внешняя флэш-память.

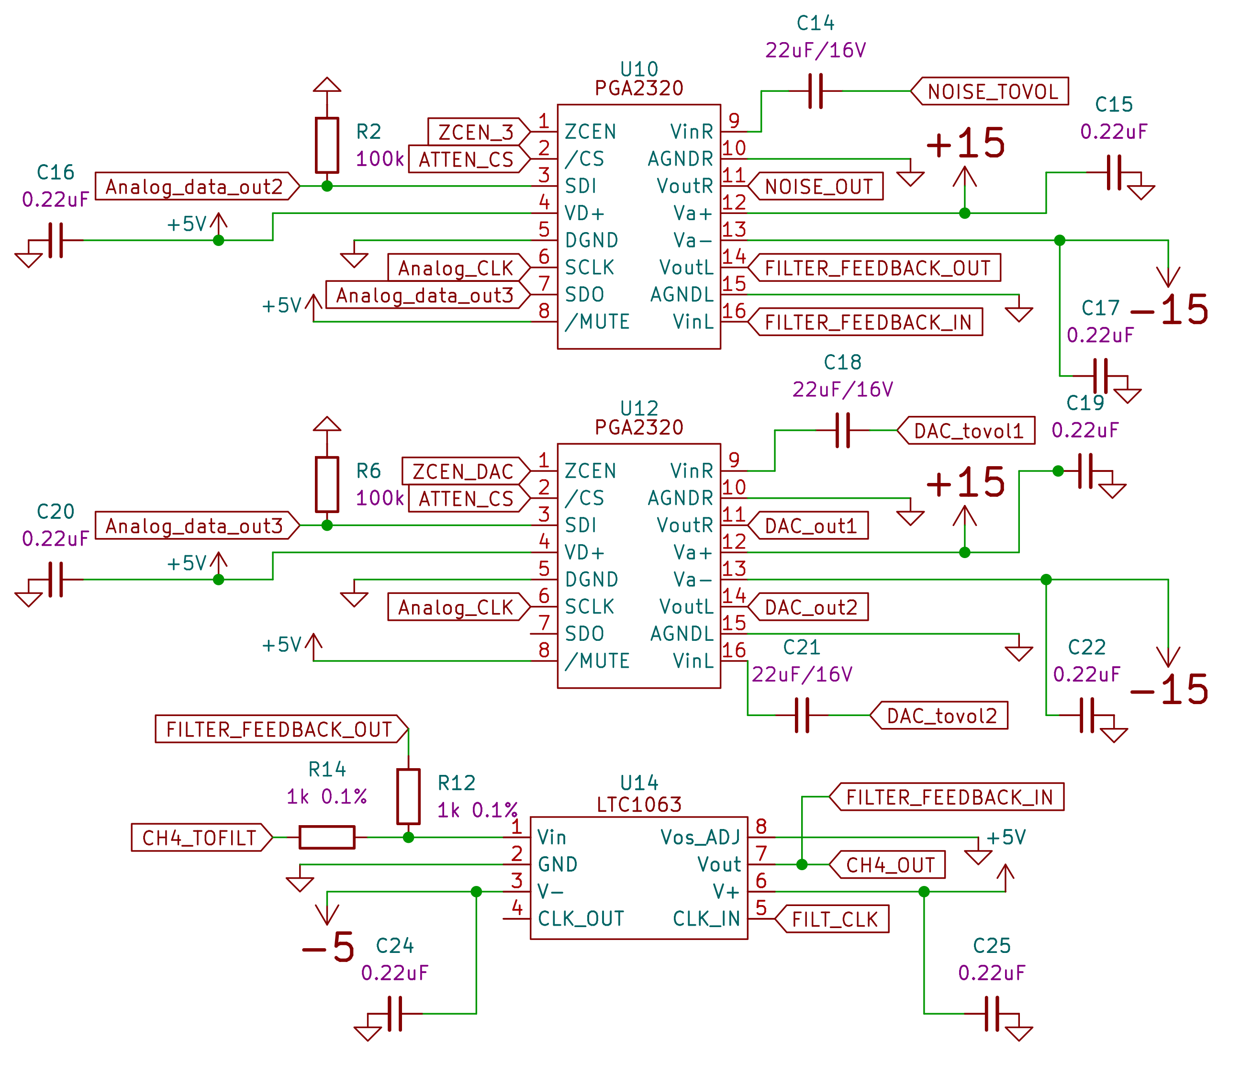
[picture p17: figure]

Рисунок Г.6 — Электрическая принципиальная схема устройства. Программно управляемые аттенюаторы каналов ЦАПов и канала шума, а также контроля обратной связи ФНЧ. Схема подключения ФНЧ.

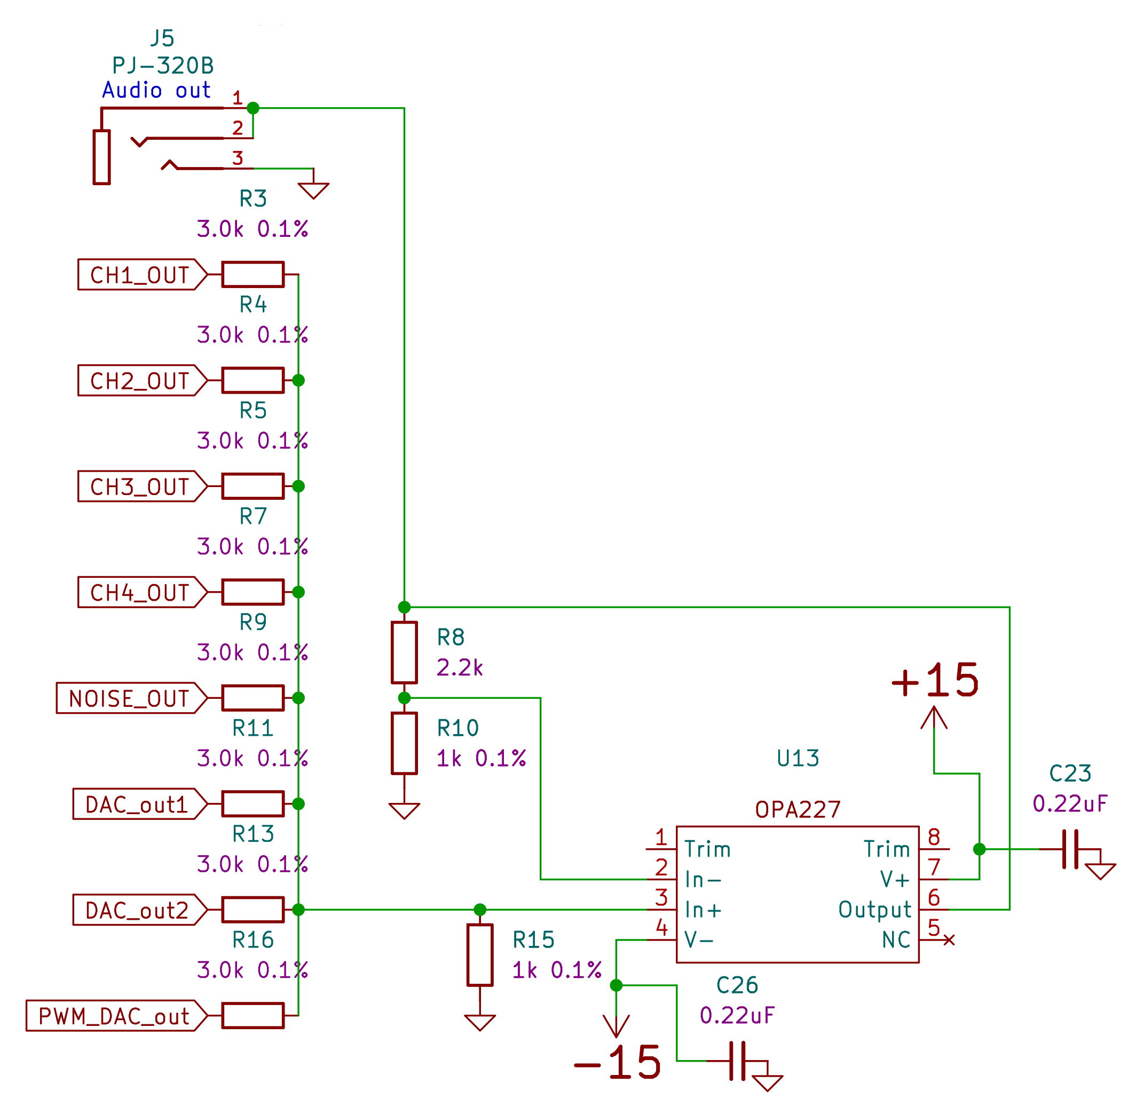
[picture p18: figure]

Рисунок Г.7 — Электрическая принципиальная схема устройства. Аналоговый неинвертирующий сумматор восьми сигналов на операционном усилителе.

# Список литературы

1. Kirn, Peter. Real World Digital Audio. Berkeley, Calif.: Peachpit Press, 2006. — 615 pp.

2. Kroupa V. F. Direct Digital Frequency Synthesizers. New York: Institute of Electrical and Electronics Engineers, 1999. — 383 pp.

3. SoundOnSound: Synthesizing Strings: PWM & String Sounds. URL: https://www.soundonsound.com/techniques/synthesizing-strings-pwm-string-sounds (дата обращения: 07.11.2024).

4. Synthesizer Basics. The musician's reference for creating, performing, and recording electronic music. Milwaukee, WI: H. Leonard Books, 1988. — 129 pp.

5. Boulanger, Richard. The Audio Programming Book. / Richard Boulanger, Victor Lazzarini. — Cambridge: MIT Press, 2010. — 920 pp.

6. Commodore 64 Programmer's Reference Guide. Wayne, Pennsylvania: Commodore Business Machines, Inc. URL: http://cini.classiccmp.org//pdf/Commodore/C64%20Programmer's%20Reference%20Guide.pdf (дата обращения: 13.11.2024).

7. Analog Devices. LTC1063 - DC Accurate, Clock-Tunable 5th Order Butterworth Lowpass Filter. URL: https://www.analog.com/media/en/technical-documentation/data-sheets/1063fa.pdf (дата обращения: 13.11.2024).

8. GitHub. STM32CrapSynth by LTVA1, main branch, STM32CrapSynthFirmware folder. URL: https://github.com/LTVA1/STM32CrapSynth/tree/main/STM32CrapSynthFirmware (дата обращения: 03.12.2024).

9. GitHub. STM32CrapSynth by LTVA1, main branch, pc_program folder. URL: https://github.com/LTVA1/STM32CrapSynth/tree/main/pc_program (дата обращения: 03.12.2024).

10. GitHub. Furnace Tracker by tildearrow, fork by LTVA1, stm32crapsynth branch. URL: https://github.com/LTVA1/furnace/tree/stm32crapsynth (дата обращения: 19.11.2024).

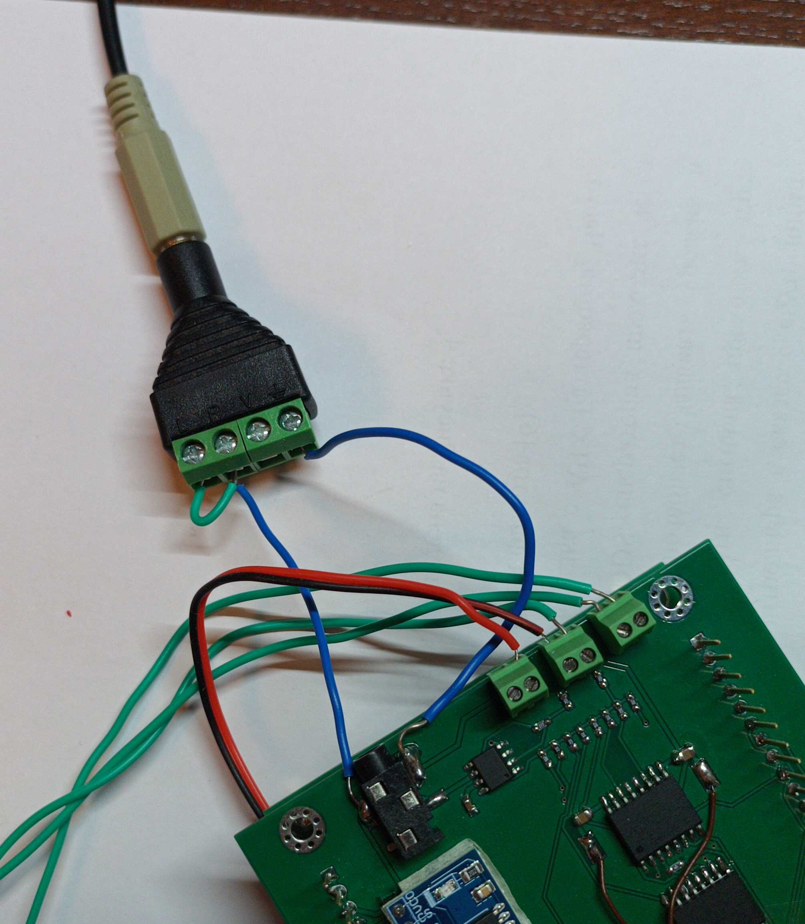
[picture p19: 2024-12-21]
pictures/audio_jack_connection.jpg

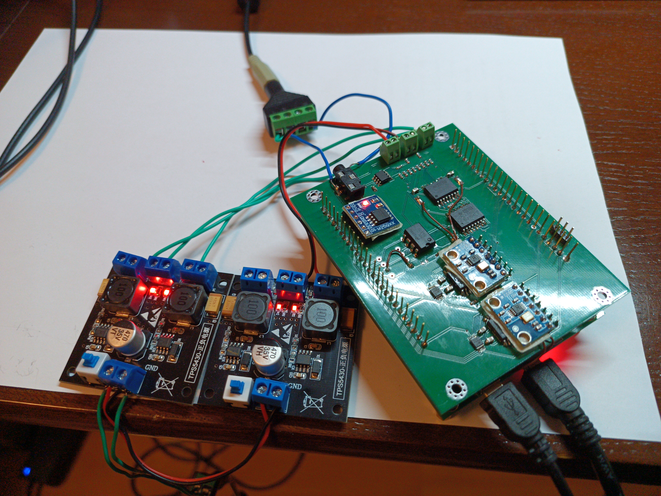
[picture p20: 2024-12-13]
device.jpg

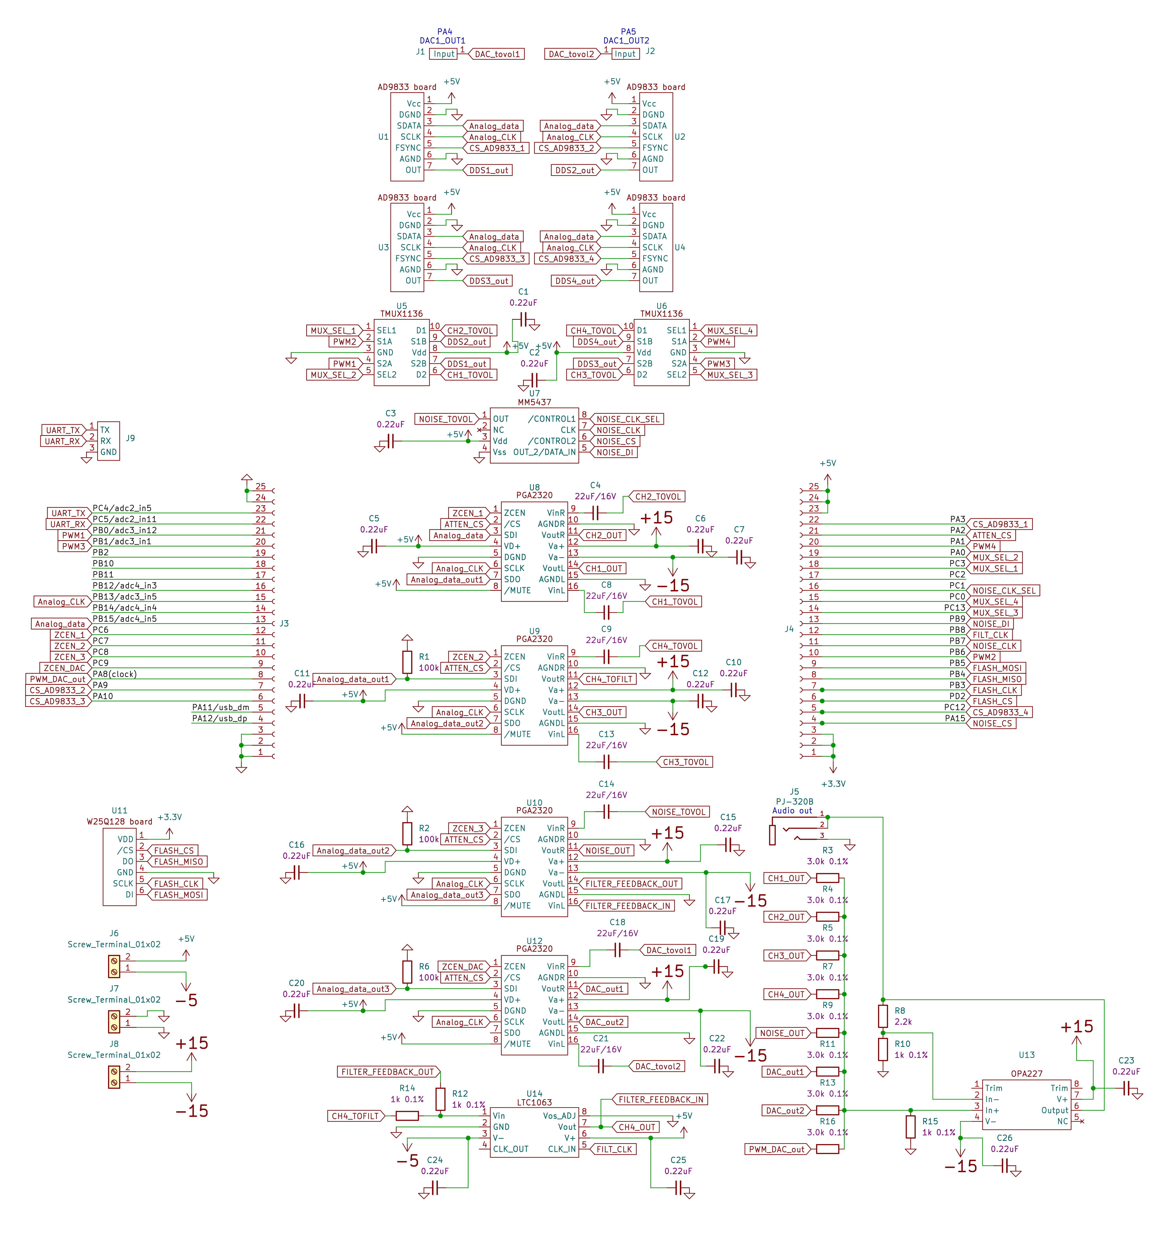
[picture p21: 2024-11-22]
board/board.png

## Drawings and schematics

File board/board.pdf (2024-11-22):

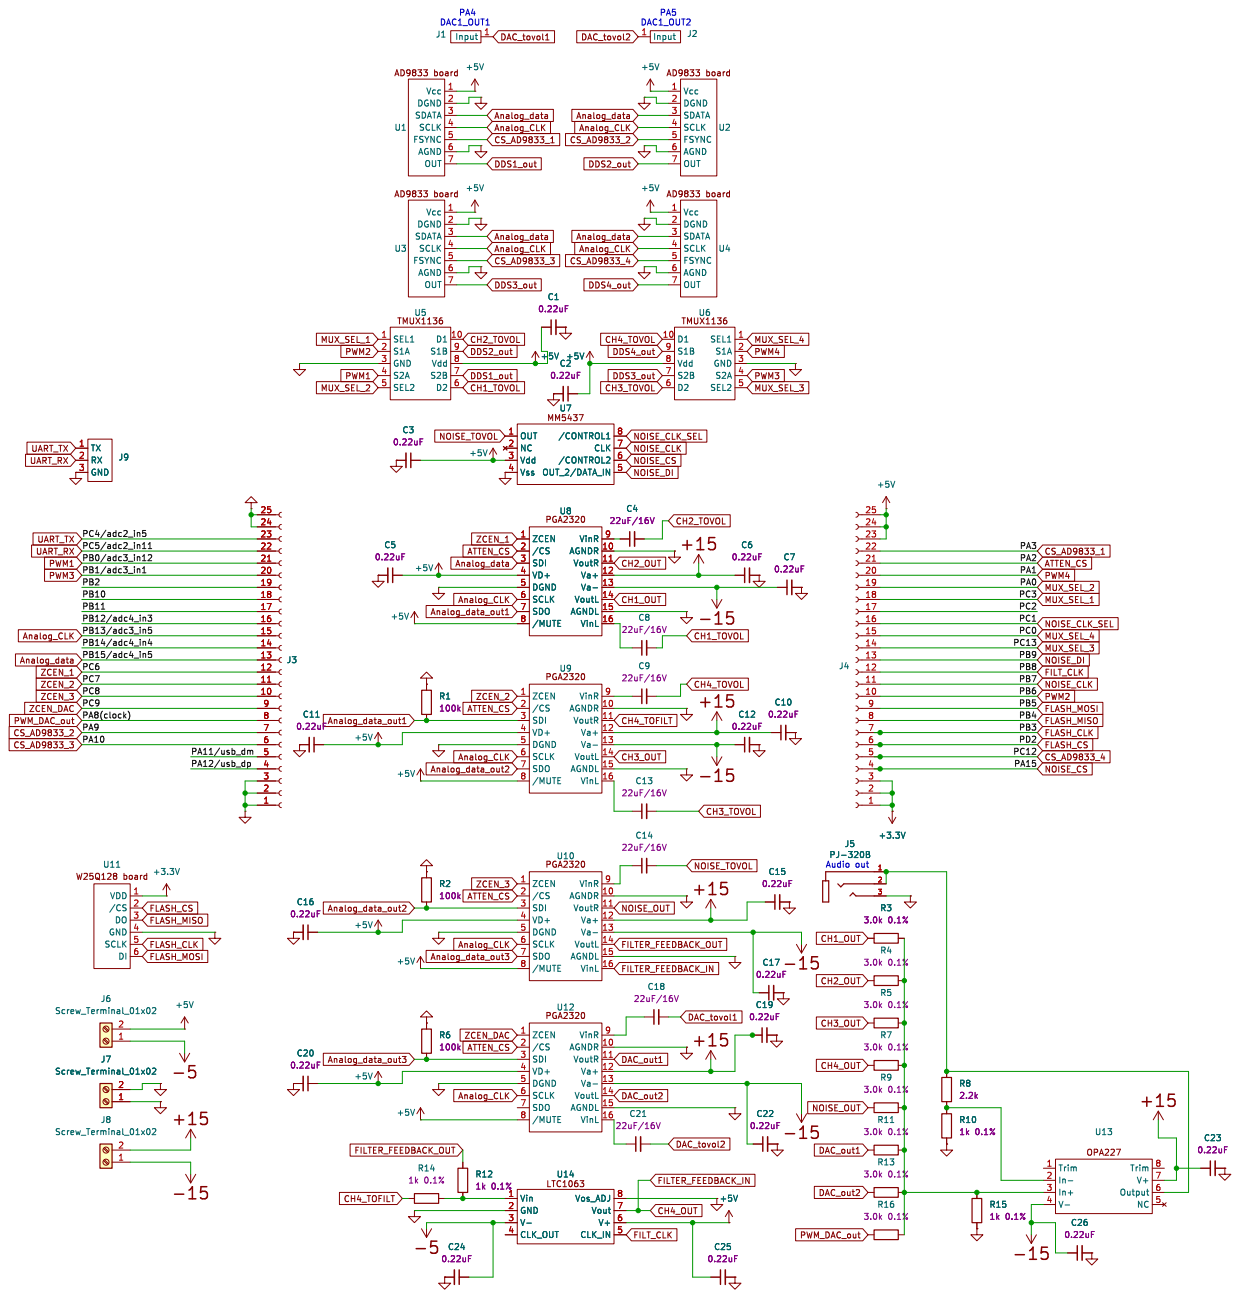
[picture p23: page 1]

AD9833 board Vcc 1 DGND 2 SDATA 3 SCLK 4 FSYNC 5 AGND 6 OUT 7 U3

/CS 2 SDI 3 VD+ 4 DGND 5 SCLK 6 SDO 7

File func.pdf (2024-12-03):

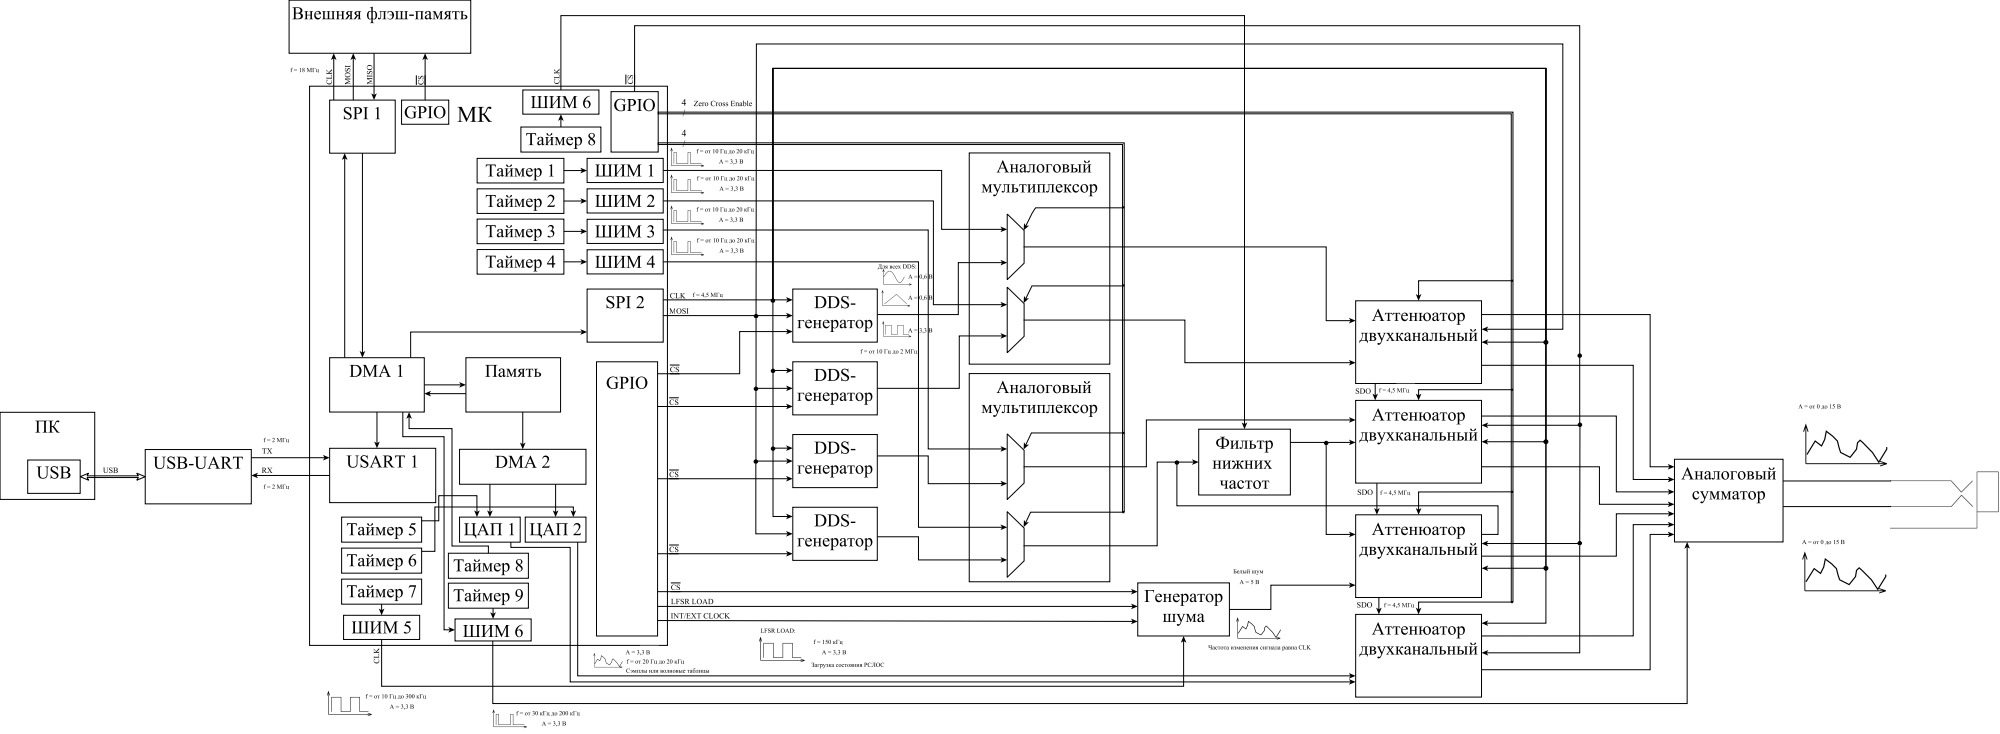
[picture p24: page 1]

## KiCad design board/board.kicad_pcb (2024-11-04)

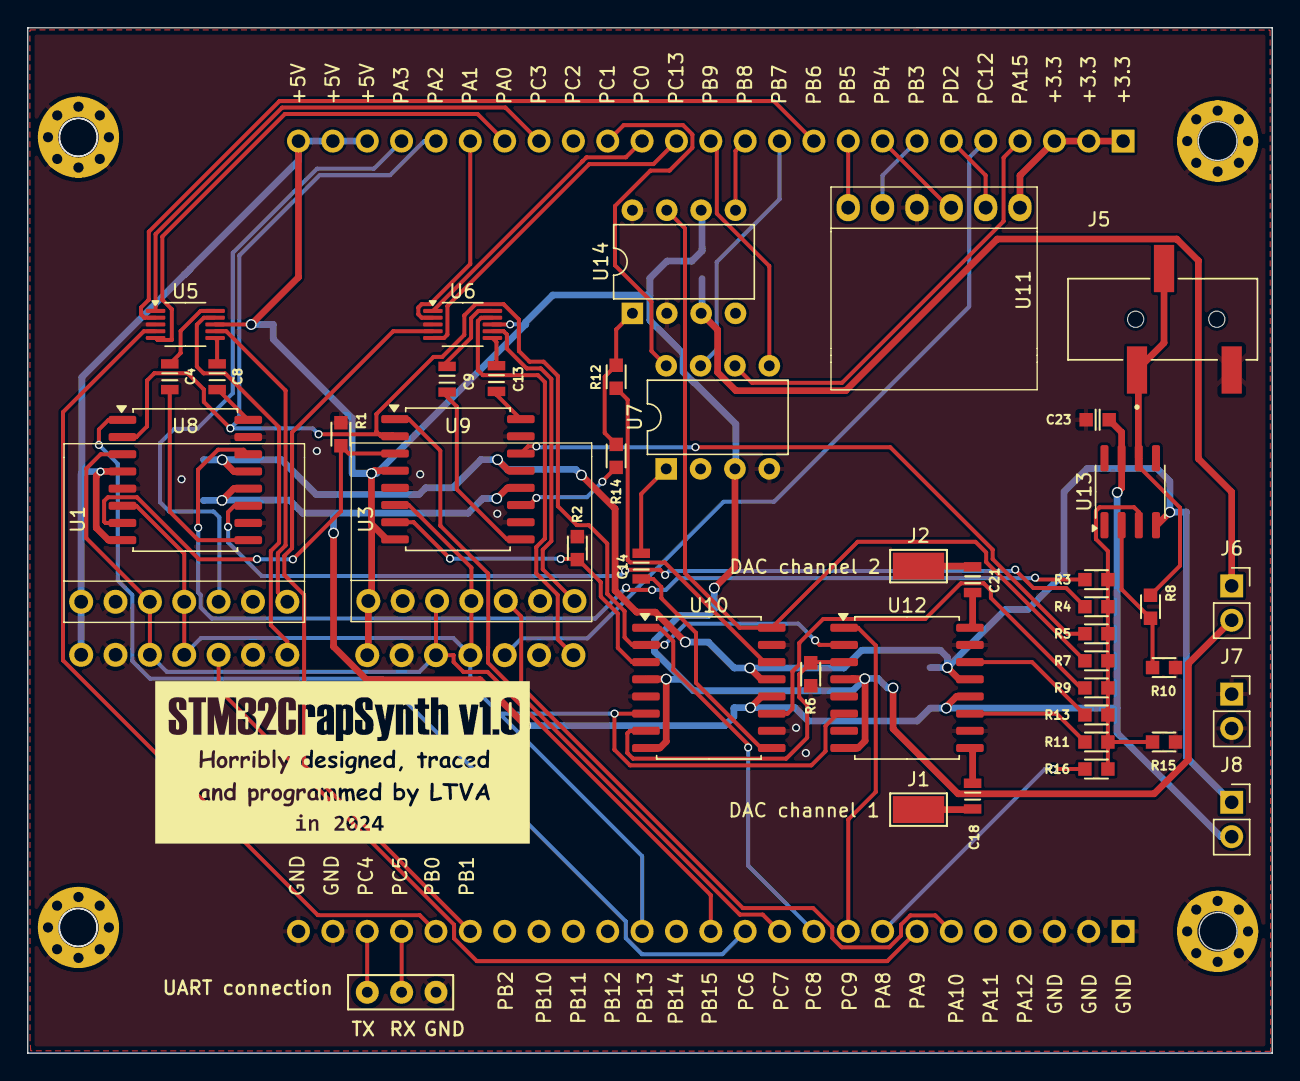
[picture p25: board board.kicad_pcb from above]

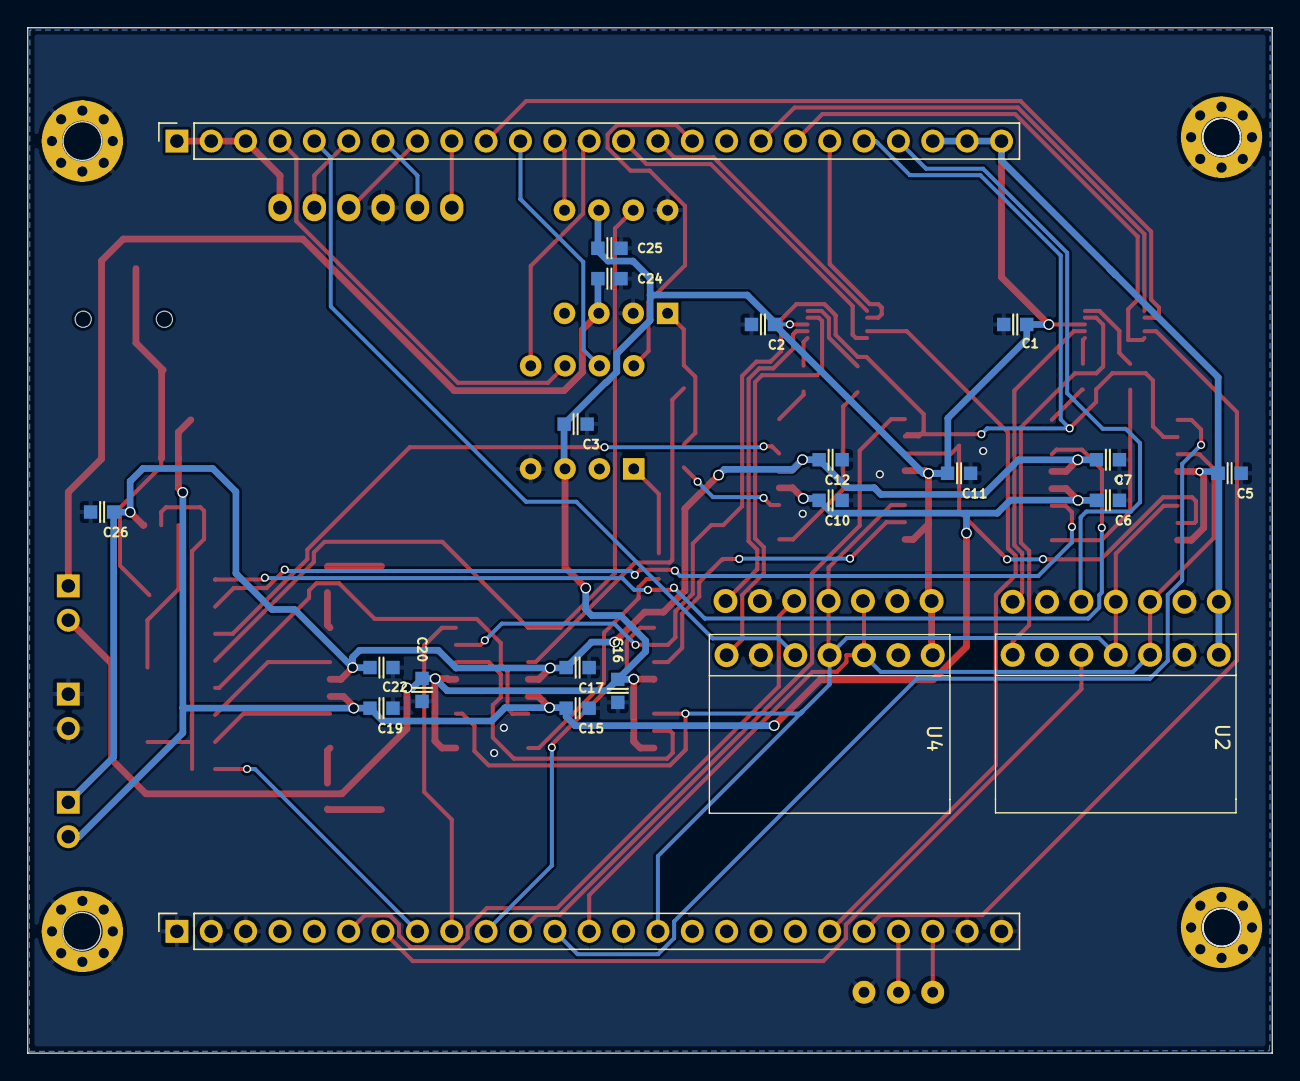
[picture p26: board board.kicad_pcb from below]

Board: 2 copper layers, 92.0 x 75.8 mm, 69 parts (23 on the bottom side), 71 nets.

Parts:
C1, C2, C3, C5, C6, C7, C10, C11, C12, C15, C16, C17, C19, C20, C22, C23, C24, C25, C26: 0.22uF_0603_25V; C_0603
C4, C8, C9, C13, C14, C18, C21: 22uF_0603_16V; C_0805
J1, J2: TestPoint_Keystone_5019_Minature
J2#2, J3, J4, J5#2: Conn_01x01; M3
J3#2, J4#2: Conn_01x25_Socket; PinSocket_1x25_P2.54mm_Vertical
J5: PJ-320B; BOOMELE_PJ-320B
J6, J7, J8: Screw_Terminal_01x02; Socket_1x02_2.54mm_TH
J9: UART_port
R1, R2, R6: 100k_0603; R_0603
R3, R4, R5, R7, R9, R11, R13, R16: 3.0k_0603_0.1%; R_0603
R8: 2.2k_0603; R_0603
R10, R12, R14, R15: 1k_0603_0.1%; R_0603
U1, U2, U3, U4: AD9833
U5, U6: VSSOP-10_3x3mm_P0.5mm
U7, U14: DIP-8pin_TH
U8, U9, U10, U12: SOIC-16W_7.5x10.3mm_P1.27mm
U11: W25Q128_board
U13: SOIC-8_3.9x4.9mm_P1.27mm

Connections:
+3.3V: J4#2.1, J4#2.2, J4#2.3, U11.1 (VDD)
+5V: C1.1, C2.1, C3.1, C5.1, C11.1, C16.1, C20.1, C25.1, J4#2.23, J4#2.24, J4#2.25, J6.2, U1.1 (Vcc), U2.1 (Vcc), U3.1 (Vcc), U4.1 (Vcc), U5.8 (Vdd), U6.8 (Vdd), U7.3 (Vdd), U8.4 (VD+), U8.8 (/MUTE), U9.4 (VD+), U9.8 (/MUTE), U10.4 (VD+), U10.8 (/MUTE), U12.4 (VD+), U12.8 (/MUTE), U14.6 (V+)
ATTEN_CS: J4#2.21, U8.2 (/CS), U9.2 (/CS), U10.2 (/CS), U12.2 (/CS)
Analog_CLK: J3#2.15, U1.4 (SCLK), U2.4 (SCLK), U3.4 (SCLK), U4.4 (SCLK), U8.6 (SCLK), U9.6 (SCLK), U10.6 (SCLK), U12.6 (SCLK)
Analog_data: J3#2.13, U1.3 (SDATA), U2.3 (SDATA), U3.3 (SDATA), U4.3 (SDATA), U8.3 (SDI)
Analog_data_out1: R1.2, U8.7 (SDO), U9.3 (SDI)
Analog_data_out2: R2.2, U9.7 (SDO), U10.3 (SDI)
Analog_data_out3: R6.2, U10.7 (SDO), U12.3 (SDI)
CH1_OUT: R3.1, U8.14 (VoutL)
CH1_TOVOL: C8.2, U5.6 (D2)
CH2_OUT: R4.1, U8.11 (VoutR)
CH2_TOVOL: C4.2, U5.10 (D1)
CH3_OUT: R5.1, U9.14 (VoutL)
CH3_TOVOL: C13.2, U6.6 (D2)
CH4_OUT: R7.1, U10.16 (VinL), U14.7 (Vout)
CH4_TOFILT: R14.2, U9.11 (VoutR)
CH4_TOVOL: C9.2, U6.10 (D1)
CS_AD9833_1: J4#2.22, U1.5 (FSYNC)
CS_AD9833_2: J3#2.7, U2.5 (FSYNC)
CS_AD9833_3: J3#2.6, U3.5 (FSYNC)
CS_AD9833_4: J4#2.5, U4.5 (FSYNC)
DAC_out1: R11.1, U12.11 (VoutR)
DAC_out2: R13.1, U12.14 (VoutL)
DAC_tovol1: C18.2, J1.1 (Input)
DAC_tovol2: C21.2, J2.1 (Input)
DDS1_out: U1.7 (OUT), U5.7 (S2B)
DDS2_out: U2.7 (OUT), U5.9 (S1B)
DDS3_out: U3.7 (OUT), U6.7 (S2B)
DDS4_out: U4.7 (OUT), U6.9 (S1B)
FILTER_FEEDBACK_OUT: R12.1, U10.14 (VoutL)
FILT_CLK: J4#2.12, U14.5 (CLK_IN)
FLASH_CLK: J4#2.7, U11.5 (SCLK)
FLASH_CS: J4#2.6, U11.2 (/CS)
FLASH_MISO: J4#2.8, U11.3 (DO)
FLASH_MOSI: J4#2.9, U11.6 (DI)
GND: C1.2, C2.2, C3.2, C5.2, C6.2, C7.2, C10.2, C11.2, C12.2, C15.2, C16.2, C17.2, C19.2, C20.2, C22.2, C23.2, C24.2, C25.2, C26.2, J2#2.1, J3.1, J3#2.1, J3#2.2, J3#2.3, J3#2.24, J3#2.25, J4.1, J5.3, J5#2.1, J7.1, J7.2, J9.3 (GND), R1.1, R2.1, R6.1, R10.2, R15.2, U1.2 (DGND), U1.6 (AGND), U2.2 (DGND), U2.6 (AGND), U3.2 (DGND), U3.6 (AGND), U4.2 (DGND), U4.6 (AGND), U5.3 (GND), U6.3 (GND), U7.4 (Vss), U8.5 (DGND), U8.10 (AGNDR), U8.15 (AGNDL), U9.5 (DGND), U9.10 (AGNDR), U9.15 (AGNDL), U10.5 (DGND), U10.10 (AGNDR), U10.15 (AGNDL), U11.4 (GND), U12.5 (DGND), U12.10 (AGNDR), U12.15 (AGNDL), U14.2 (GND), U14.8 (Vos_ADJ)
MUX_SEL_1: J4#2.18, U5.1 (SEL1)
MUX_SEL_2: J4#2.19, U5.5 (SEL2)
MUX_SEL_3: J4#2.14, U6.5 (SEL2)
MUX_SEL_4: J4#2.15, U6.1 (SEL1)
NOISE_CLK: J4#2.11, U7.7 (CLK)
NOISE_CLK_SEL: J4#2.16, U7.8 (/CONTROL1)
NOISE_CS: J4#2.4, U7.6 (/CONTROL2)
NOISE_DI: J4#2.13, U7.5 (OUT_2/DATA_IN)
NOISE_OUT: R9.1, U10.11 (VoutR)
NOISE_TOVOL: C14.2, U7.1 (OUT)
unnamed: C8.1, U8.16 (VinL)
unnamed: C4.1, U8.9 (VinR)
unnamed: C13.1, U9.16 (VinL)
unnamed: C9.1, U9.9 (VinR)
unnamed: C14.1, U10.9 (VinR)
unnamed: C21.1, U12.16 (VinL)
unnamed: C18.1, U12.9 (VinR)
unnamed: R3.2, R4.2, R5.2, R7.2, R9.2, R11.2, R13.2, R15.1, R16.2, U13.3 (In+)
unnamed: R8.2, R10.1, U13.2 (In-)
unnamed: J5.1, J5.2, R8.1, U13.6 (Output)
unnamed: R12.2, R14.1, U14.1 (Vin)
P,+15: C6.1, C10.1, C15.1, C19.1, C23.1, J8.2, U8.12 (Va+), U9.12 (Va+), U10.12 (Va+), U12.12 (Va+), U13.7 (V+)
P,-5: C24.1, J6.1, U14.3 (V-)
P,-15: C7.1, C12.1, C17.1, C22.1, C26.1, J8.1, U8.13 (Va-), U9.13 (Va-), U10.13 (Va-), U12.13 (Va-), U13.4 (V-)
PWM1: J3#2.21, U5.4 (S2A)
PWM2: J4#2.10, U5.2 (S1A)
PWM3: J3#2.20, U6.4 (S2A)
PWM4: J4#2.20, U6.2 (S1A)
PWM_DAC_out: J3#2.8, R16.1
UART_RX: J3#2.22, J9.2 (RX)
UART_TX: J3#2.23, J9.1 (TX)
ZCEN_1: J3#2.12, U8.1 (ZCEN)
ZCEN_2: J3#2.11, U9.1 (ZCEN)
ZCEN_3: J3#2.10, U10.1 (ZCEN)
ZCEN_DAC: J3#2.9, U12.1 (ZCEN)

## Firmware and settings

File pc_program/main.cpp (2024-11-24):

#include <iostream>
#include "serialib.h" // https://github.com/imabot2/serialib
#include "string.h"
#include <stdio.h>
#include <stdint.h>

#define FILE_VERSION 1

#define FLASH_BLOCK_SIZE 2048
#define RAM_BLOCK_SIZE 2048
#define EXT_FLASH_BLOCK_SIZE 2048

#define SYNTH_SYNC_BYTE 0x69

#define SYNTH_CMD_LOAD_FLASH 0
#define SYNTH_CMD_LOAD_RAM 1
#define SYNTH_CMD_LOAD_EXT_FLASH 2
#define SYNTH_CMD_PLAYBACK_START 3
#define SYNTH_CMD_PLAYBACK_STOP 4
#define SYNTH_CMD_MAX 5

#define SYNTH_RESPONSE_SIZE 48

#define SYNTH_RESPONSE_READY 0
#define SYNTH_RESPONSE_FLASH_BLOCK 1
#define SYNTH_RESPONSE_RAM_BLOCK 2
#define SYNTH_RESPONSE_EXTERNAL_FLASH_BLOCK 3
#define SYNTH_RESPONSE_BAD_XOR 4
#define SYNTH_RESPONSE_UNKNOWN_COMMAND 5

//#define MCU_FIRMWARE_SIZE (50 * 1024) /*TODO: replace with final size*/
//#define BASE_ADDR_FLASH 0x08000000 + MCU_FIRMWARE_SIZE
//#define BASE_ADDR_RAM 0x20000000 /*TODO: replace with final array addr*/

int load_file(serialib serial)
{
	uint32_t MCU_FIRMWARE_SIZE = 0;
	uint32_t BASE_ADDR_FLASH = 0;
	uint32_t BASE_ADDR_RAM = 0;
	uint32_t SUPPORTED_FILE_VERSION = 0;
	uint32_t FIRMWARE_VERSION = 0;
	uint32_t EXTERNAL_FLASH_SIZE = 0;
	uint64_t EXTERNAL_FLASH_UID = 0;
	uint8_t EXTERNAL_FLASH_MANUFACTURER_ID = 0;

	uint8_t our_xor = 0;

	unsigned char txbuf[4096] = {0};
	unsigned char rxbuf[4096] = {0};

	serial.readBytes(rxbuf, SYNTH_RESPONSE_SIZE);

	for(int i = 0; i < SYNTH_RESPONSE_SIZE - 1; i++)
	{
		our_xor ^= rxbuf[i];
	}

	if(our_xor != rxbuf[SYNTH_RESPONSE_SIZE - 1])
	{
		std::cout << "Wrong checksum in comms establishing packet!" << std::endl;
		return -1;
	}

	if(rxbuf[1] != SYNTH_RESPONSE_READY)
	{
		std::cout << "Wrong packet ID in comms establishing packet!" << std::endl;
		return -1;
	}

	//TODO: uncomment

	MCU_FIRMWARE_SIZE = (uint32_t)rxbuf[5] + ((uint32_t)rxbuf[4] << 8) + ((uint32_t)rxbuf[3] << 16) + ((uint32_t)rxbuf[2] << 24);
	BASE_ADDR_FLASH = (uint32_t)rxbuf[9] + ((uint32_t)rxbuf[8] << 8) + ((uint32_t)rxbuf[7] << 16) + ((uint32_t)rxbuf[6] << 24);
	BASE_ADDR_RAM = (uint32_t)rxbuf[13] + ((uint32_t)rxbuf[12] << 8) + ((uint32_t)rxbuf[11] << 16) + ((uint32_t)rxbuf[10] << 24);

	SUPPORTED_FILE_VERSION = (uint32_t)rxbuf[17] + ((uint32_t)rxbuf[16] << 8) + ((uint32_t)rxbuf[15] << 16) + ((uint32_t)rxbuf[14] << 24);
	FIRMWARE_VERSION = (uint32_t)rxbuf[21] + ((uint32_t)rxbuf[20] << 8) + ((uint32_t)rxbuf[19] << 16) + ((uint32_t)rxbuf[18] << 24);
	EXTERNAL_FLASH_SIZE = (uint32_t)rxbuf[25] + ((uint32_t)rxbuf[24] << 8) + ((uint32_t)rxbuf[23] << 16) + ((uint32_t)rxbuf[22] << 24);
	EXTERNAL_FLASH_UID = (uint64_t)rxbuf[33] + ((uint64_t)rxbuf[32] << 8) + ((uint64_t)rxbuf[31] << 16) + ((uint64_t)rxbuf[30] << 24)
		 + ((uint64_t)rxbuf[29] << 32) + ((uint64_t)rxbuf[28] << 40) + ((uint64_t)rxbuf[27] << 48) + ((uint64_t)rxbuf[26] << 56);
	EXTERNAL_FLASH_MANUFACTURER_ID = rxbuf[34];

	//EXTERNAL_FLASH_SIZE = 1024 * 1024 * 16; //16 MiB TODO: remove when actual comms are established

	char buffer_cout[1666] = {0};

	snprintf(buffer_cout, 1666, 
		"\nSTM32CrapSynth responded!\n"
		"Firmware version: %d.%d.%d.%d\n"
		"MCU firmware size: 0x%08X\n"
		"Samples range in Flash starting address: 0x%08X\n"
		"Samples array in RAM starting address: 0x%08X\n"
		"Highest supported .scs file version: %d.%d.%d.%d\n"
		"External Flash memory size: %d bytes (%d%s)\n"
		"External Flash memory UID: 0x%016llX\n"
		"External Flash manufacturer ID: 0x%02X\n",
			rxbuf[21], rxbuf[20], rxbuf[19], rxbuf[18],
			MCU_FIRMWARE_SIZE,
			BASE_ADDR_FLASH,
			BASE_ADDR_RAM,
			rxbuf[17], rxbuf[16], rxbuf[15], rxbuf[14],
			EXTERNAL_FLASH_SIZE, //%d bytes
			EXTERNAL_FLASH_SIZE > 1024 * 1024 ? EXTERNAL_FLASH_SIZE / (1024 * 1024) : EXTERNAL_FLASH_SIZE / 1024, //%d
			EXTERNAL_FLASH_SIZE > 1024 * 1024 ? "MiB" : "KiB", //%s
			EXTERNAL_FLASH_UID,
			EXTERNAL_FLASH_MANUFACTURER_ID);
	
	std::cout << buffer_cout << std::endl;

	txbuf[0] = SYNTH_SYNC_BYTE;

	std::cout << "\nEnter STM32CrapSynth file name:\n" << std::endl;

	std::string filename;
	std::cin >> filename;

	FILE* f = fopen(filename.c_str(), "rb");

	if(f == NULL)
	{
		std::cout << "Couldn't open file!" << std::endl;
		fclose(f);
		return -1;
	}
	if(fseek(f, 59, SEEK_SET) != 0)
	{
		std::cout << "Error, file too short!" << std::endl;
		fclose(f);
		return -1;
	}

	fseek(f, 0, SEEK_SET);

	char magic[5] = {0};
	fread(magic, 4, 1, f);
	magic[4] = '\0';

	if(strncmp(magic, "CRAP", 5) != 0)
	{
		std::cout << "Bad file signature: \"" << magic << "\"!" << std::endl;
		fclose(f);
		return -1;
	}
	uint32_t version = 0;
	fread(&version, sizeof(uint32_t), 1, f);

	if(version > FILE_VERSION)
	{
		std::cout << "File version too high: " << version << "!" << std::endl;
		fclose(f);
		return -1;
	}
	uint32_t size = 0;
	fread(&size, sizeof(uint32_t), 1, f);

	char flashsamples[20] = {0};
	fread(flashsamples, 13, 1, f);
	flashsamples[13] = '\0';

	if(strncmp(flashsamples, "FLASH SAMPLES", 14) != 0)
	{
		std::cout << "Bad flash samples block signature: \"" << flashsamples << "\"!" << std::endl;
		fclose(f);
		return -1;
	}

	std::cout << "\nWriting data...\n" << std::endl;

	uint32_t flash_samples_size = 0;
	fread(&flash_samples_size, sizeof(uint32_t), 1, f);

	if(flash_samples_size > 0)
	{
		uint32_t flash_samples_pos = 0;

		std::cout << "\nWriting flash samples " << "(" << flash_samples_size << " bytes)...\n" << std::endl;

		while(flash_samples_pos < flash_samples_size - 1)
		{
			uint32_t block_size = ((flash_samples_size - flash_samples_pos) > FLASH_BLOCK_SIZE ? FLASH_BLOCK_SIZE : (flash_samples_size - flash_samples_pos));
			uint8_t data_xor = 0;

			txbuf[1] = (block_size + 8) >> 8;
			txbuf[2] = (block_size + 8) & 0xff;
			txbuf[3] = SYNTH_CMD_LOAD_FLASH;

			txbuf[4] = (flash_samples_pos) & 0xff;
			txbuf[5] = ((flash_samples_pos) >> 8) & 0xff;
			txbuf[6] = ((flash_samples_pos) >> 16) & 0xff;
			txbuf[7] = ((flash_samples_pos) >> 24) & 0xff;

			for(int i = 0; i < block_size; i++) //fill buffer
			{
				fread(&txbuf[8 + i], 1, 1, f);
			}
			for(int i = 0; i < block_size + 8; i++)
			{
				data_xor ^= txbuf[i];
			}

			for(int i = 0; i < 8; i++)
			{
				//snprintf(buffer_cout, 666, "%d %02X", txbuf[i], txbuf[i]);
				//std::cout << buffer_cout << std::endl;
			}

			txbuf[8 + block_size] = data_xor;
			
			snprintf(buffer_cout, 666, "Writing flash samples, block size %d bytes: 0x%08X-0x%08X (%.2f%)", block_size, BASE_ADDR_FLASH + flash_samples_pos, BASE_ADDR_FLASH + flash_samples_pos + block_size, (double)(flash_samples_pos) * 100.0 / (double)flash_samples_size);
			std::cout << buffer_cout << std::endl;

			serial.writeBytes(txbuf, 8 + block_size + 1);

			flash_samples_pos += block_size;

			serial.readBytes(rxbuf, SYNTH_RESPONSE_SIZE);
			our_xor = 0;

			for(int i = 0; i < SYNTH_RESPONSE_SIZE - 1; i++)
			{
				our_xor ^= rxbuf[i];
			}

			if(our_xor != rxbuf[SYNTH_RESPONSE_SIZE - 1])
			{
				std::cout << "Wrong checksum in Flash block receive confirmation packet!" << std::endl;
				fclose(f);
				return -1;
			}

			if(rxbuf[1] != SYNTH_RESPONSE_FLASH_BLOCK)
			{
				std::cout << "Wrong packet ID in Flash block receive confirmation packet: " << rxbuf[1] << "!" << std::endl;
				fclose(f);
				return -1;
			}

			if(rxbuf[2] != data_xor)
			{
				std::cout << "Wrong data checksum in Flash block receive confirmation packet!" << std::endl;
				fclose(f);
				return -1;
			}

			uint32_t mcu_response_start_addr = (uint32_t)rxbuf[3] + ((uint32_t)rxbuf[4] << 8) + ((uint32_t)rxbuf[5] << 16) + ((uint32_t)rxbuf[6] << 24);

			if(mcu_response_start_addr != flash_samples_pos - block_size)
			{
				std::cout << "Wrong data start position in Flash block receive confirmation packet!" << std::endl;
				fclose(f);
				return -1;
			}

			uint32_t mcu_response_data_len = (uint32_t)rxbuf[7] + ((uint32_t)rxbuf[8] << 8);

			if(mcu_response_data_len != block_size)
			{
				std::cout << "Wrong block length telemetry in Flash block receive confirmation packet: " << (int)mcu_response_data_len << "!" << std::endl;
				fclose(f);
				return -1;
			}

			//TODO: uncomment
		}
	}

	char ramsamples[20] = {0};
	fread(ramsamples, 11, 1, f);
	ramsamples[12] = '\0';

	if(strncmp(ramsamples, "RAM SAMPLES", 12) != 0)
	{
		std::cout << "Bad RAM samples block signature: \"" << ramsamples << "\"!" << std::endl;
		fclose(f);
		return -1;
	}

	uint16_t ram_samples_size = 0;
	fread(&ram_samples_size, sizeof(uint16_t), 1, f);

	if(ram_samples_size > 0)
	{
		std::cout << "\nWriting RAM samples " << "(" << ram_samples_size << " bytes)...\n" << std::endl;

		uint16_t ram_samples_pos = 0;

		while(ram_samples_pos < ram_samples_size - 1)
		{
			uint32_t block_size = ((ram_samples_size - ram_samples_pos) > RAM_BLOCK_SIZE ? RAM_BLOCK_SIZE : (ram_samples_size - ram_samples_pos));
			uint8_t data_xor = 0;

			txbuf[1] = (block_size + 8) >> 8;
			txbuf[2] = (block_size + 8) & 0xff;
			txbuf[3] = SYNTH_CMD_LOAD_RAM;

			txbuf[4] = (ram_samples_pos) & 0xff;
			txbuf[5] = ((ram_samples_pos) >> 8) & 0xff;
			txbuf[6] = ((ram_samples_pos) >> 16) & 0xff;
			txbuf[7] = ((ram_samples_pos) >> 24) & 0xff;

			for(int i = 0; i < block_size; i++) //fill buffer
			{
				fread(&txbuf[8 + i], 1, 1, f);
			}
			for(int i = 0; i < block_size + 8; i++)
			{
				data_xor ^= txbuf[i];
			}

			txbuf[8 + block_size] = data_xor;

			snprintf(buffer_cout, 666, "Writing RAM samples, block size %d bytes: 0x%08X-0x%08X (%.2f%)", block_size, BASE_ADDR_RAM + ram_samples_pos, BASE_ADDR_RAM + ram_samples_pos + block_size, (double)(ram_samples_pos) * 100.0 / (double)ram_samples_size);
			std::cout << buffer_cout << std::endl;

			serial.writeBytes(txbuf, 8 + block_size + 1);

			ram_samples_pos += block_size;

			serial.readBytes(rxbuf, SYNTH_RESPONSE_SIZE);
			our_xor = 0;

			for(int i = 0; i < SYNTH_RESPONSE_SIZE - 1; i++)
			{
				our_xor ^= rxbuf[i];
			}

			if(our_xor != rxbuf[SYNTH_RESPONSE_SIZE - 1])
			{
				std::cout << "Wrong checksum in RAM block receive confirmation packet!" << std::endl;
				fclose(f);
				return -1;
			}

			if(rxbuf[1] != SYNTH_RESPONSE_RAM_BLOCK)
			{
				std::cout << "Wrong packet ID in RAM block receive confirmation packet: " << rxbuf[1] << "!" << std::endl;
				fclose(f);
				return -1;
			}

			if(rxbuf[2] != data_xor)
			{
				std::cout << "Wrong data checksum in RAM block receive confirmation packet!" << std::endl;
				fclose(f);
				return -1;
			}

			uint32_t mcu_response_start_addr = (uint32_t)rxbuf[3] + ((uint32_t)rxbuf[4] << 8) + ((uint32_t)rxbuf[5] << 16) + ((uint32_t)rxbuf[6] << 24);

			if(mcu_response_start_addr != ram_samples_pos - block_size)
			{
				std::cout << "Wrong data start position in RAM block receive confirmation packet!" << std::endl;
				fclose(f);
				return -1;
			}

			uint32_t mcu_response_data_len = (uint32_t)rxbuf[7] + ((uint32_t)rxbuf[8] << 8);

			if(mcu_response_data_len != block_size)
			{
				std::cout << "Wrong block length telemetry in RAM block receive confirmation packet!" << std::endl;
				fclose(f);
				return -1;
			}

			//TODO: uncomment
		}
	}

	char regdump[20] = {0};
	fread(regdump, 14, 1, f);
	regdump[15] = '\0';

	if(strncmp(regdump, "REGISTERS DUMP", 15) != 0)
	{
		std::cout << "Bad registers dump block signature: \"" << regdump << "\"!" << std::endl;
		fclose(f);
		return -1;
	}

	uint32_t regdump_size = 0;
	fread(&regdump_size, sizeof(uint32_t), 1, f);

	if(regdump_size > 0)
	{
		if(regdump_size > EXTERNAL_FLASH_SIZE)
		{
			std::cout << "Registers dump block is bigger than external Flash memory!" << std::endl;
			std::cout << "Exactly by " << regdump_size - EXTERNAL_FLASH_SIZE << " bytes, if you're curious." << std::endl;
			std::cout << "External Flash size is " << EXTERNAL_FLASH_SIZE << " bytes when regdump is " << regdump_size << " bytes." << std::endl;
			fclose(f);
			return -1;
		}

		std::cout << "\nWriting data (registers dump and wavetable data) to external flash " << "(" << regdump_size << " bytes)...\n" << std::endl;

		uint32_t regdump_pos = 0;

		while(regdump_pos < regdump_size - 1)
		{
			uint32_t block_size = ((regdump_size - regdump_pos) > EXT_FLASH_BLOCK_SIZE ? EXT_FLASH_BLOCK_SIZE : (regdump_size - regdump_pos));
			uint8_t data_xor = 0;

			txbuf[1] = (block_size + 8) >> 8;
			txbuf[2] = (block_size + 8) & 0xff;
			txbuf[3] = SYNTH_CMD_LOAD_EXT_FLASH;

			txbuf[4] = (regdump_pos) & 0xff;
			txbuf[5] = ((regdump_pos) >> 8) & 0xff;
			txbuf[6] = ((regdump_pos) >> 16) & 0xff;
			txbuf[7] = ((regdump_pos) >> 24) & 0xff;

			for(int i = 0; i < block_size; i++) //fill buffer
			{
				fread(&txbuf[8 + i], 1, 1, f);
			}
			for(int i = 0; i < block_size + 8; i++)
			{
				data_xor ^= txbuf[i];
			}

			txbuf[8 + block_size] = data_xor;

			snprintf(buffer_cout, 666, "Writing external flash, block size %d bytes: 0x%08X-0x%08X (%.2f%)", block_size, regdump_pos, regdump_pos + block_size, (double)(regdump_pos) * 100.0 / (double)regdump_size);
			std::cout << buffer_cout << std::endl;

			serial.writeBytes(txbuf, 8 + block_size + 1);

			regdump_pos += block_size;

			serial.readBytes(rxbuf, SYNTH_RESPONSE_SIZE);
			our_xor = 0;

			for(int i = 0; i < SYNTH_RESPONSE_SIZE - 1; i++)
			{
				our_xor ^= rxbuf[i];
			}

			if(our_xor != rxbuf[SYNTH_RESPONSE_SIZE - 1])
			{
				std::cout << "Wrong checksum in external Flash block receive confirmation packet!" << std::endl;
				fclose(f);
				return -1;
			}

			if(rxbuf[1] != SYNTH_RESPONSE_EXTERNAL_FLASH_BLOCK)
			{
				std::cout << "Wrong packet ID in external Flash block receive confirmation packet: " << rxbuf[1] << "!" << std::endl;
				fclose(f);
				return -1;
			}

			if(rxbuf[2] != data_xor)
			{
				std::cout << "Wrong data checksum in external Flash block receive confirmation packet!" << std::endl;
				fclose(f);
				return -1;
			}

			uint32_t mcu_response_start_addr = (uint32_t)rxbuf[3] + ((uint32_t)rxbuf[4] << 8) + ((uint32_t)rxbuf[5] << 16) + ((uint32_t)rxbuf[6] << 24);

			if(mcu_response_start_addr != regdump_pos - block_size)
			{
				std::cout << "Wrong data start position in external Flash block receive confirmation packet!" << std::endl;
				fclose(f);
				return -1;
			}

			uint32_t mcu_response_data_len = (uint32_t)rxbuf[7] + ((uint32_t)rxbuf[8] << 8);

			if(mcu_response_data_len != block_size)
			{
				std::cout << "Wrong block length telemetry in external Flash block receive confirmation packet!" << std::endl;
				fclose(f);
				return -1;
			}

			//TODO: uncomment
		}
	}

	std::cout << "\nDone writing data!\n" << std::endl;

	fclose(f);

	bool quit = false;

	int command = 0;

	while(!quit)
	{
		std::cout << "\nEnter command:\n1 - start playback\n2 - stop playback\n3 - stop playback and exit\n" << std::endl;
		std::cin >> command;

		switch(command)
		{
			case 1:
			{
				uint8_t our_xor = 0;
				
				txbuf[0] = SYNTH_SYNC_BYTE;
				txbuf[1] = 0;
				txbuf[2] = 4; //size = 4
				txbuf[3] = SYNTH_CMD_PLAYBACK_START;

				for(int i = 0; i < 4; i++)
				{
					our_xor ^= txbuf[i];
				}

				txbuf[4] = our_xor;
				serial.writeBytes(txbuf, 5);
				break;
			}
			case 2:
			case 3:
			{
				uint8_t our_xor = 0;
				
				txbuf[0] = SYNTH_SYNC_BYTE;
				txbuf[1] = 0;
				txbuf[2] = 4; //size = 4
				txbuf[3] = SYNTH_CMD_PLAYBACK_STOP;

				for(int i = 0; i < 4; i++)
				{
					our_xor ^= txbuf[i];
				}

				txbuf[4] = our_xor;
				serial.writeBytes(txbuf, 5);

				if(command == 3)
				{
					quit = true;
				}
				break;
			}
			default:
			{
				std::cout << "Unknown command!" << std::endl;
				break;
			}
		}
	}
	return 0;
}

int main() 
{
	std::cout << "Program will test each serial port and tell which ones it managed to connect to.\n" << std::endl;

	// Serial object
	serialib serial;

	char device_name[50] = { 0 };
	// Test each port between COM1 and COM99 on Windows and between /dev/ttyS0 and /dev/ttyS99 on Linux
	for (int i=1;i<99;i++)
	{
		// Prepare the port name (Windows)
		#if defined (_WIN32) || defined( _WIN64)
			sprintf (device_name,"\\\\.\\COM%d",i);
		#endif

		// Prepare the port name (Linux)
		#ifdef __linux__
			sprintf (device_name,"/dev/ttyACM%d",i-1);
		#endif

		// try to connect to the device
		if (serial.openDevice(device_name,115200)==1)
		{
			printf ("Device detected on %s\n", device_name);
			// Close the device before testing the next port
			serial.closeDevice();
		}
	}

	std::cout << "Choose port number" << std::endl;

	int num_device = -1;
	std::cin >> num_device;

#if defined (_WIN32) || defined( _WIN64)
	if(num_device > 99 || num_device <= 1)
#endif
#ifdef __linux__
	if(num_device > 100 || num_device <= 0)
#endif
	{
		std::cout << "Wrong port specified" << std::endl;
		return 0;
	}

	std::cout << "Specify baud rate" << std::endl;

	int baud = -1;
	std::cin >> baud;

#if defined (_WIN32) || defined( _WIN64)
	if(baud < 110 || baud > 2000000)
#endif
#ifdef __linux__
	if(baud < 110 || baud > 4000000)
#endif
	{
		std::cout << "Wrong baud rate specified" << std::endl;
		return 0;
	}

	#if defined (_WIN32) || defined( _WIN64)
		sprintf (device_name,"\\\\.\\COM%d",num_device);
	#endif
	#ifdef __linux__
		sprintf (device_name,"/dev/ttyACM%d",num_device);
	#endif

	// try to connect to the device
	if (serial.openDevice(device_name,baud)==1)
	{
		std::cout << "Connection successful" << std::endl;
	}
	else
	{
		std::cout << "Couldn't connect to device" << std::endl;
		serial.closeDevice();
		return 0;
	}

	bool quit = false;

	std::cout << "Power cycle your device to establish communication..." << std::endl;

	while(!quit)
	{
		load_file(serial);
	}

	serial.closeDevice();
	std::cout << "All done" << std::endl;
	return 0;
}

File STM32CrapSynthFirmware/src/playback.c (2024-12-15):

/*
 * playback.c
 *
 *  Created on: 9 ���. 2024 �.
 *      Author: georg
 */

#include "playback.h"
#include "stm32f3xx.h"
#include "main.h"
#include "commands.h"
#include "external_flash.h"
#include "gpio.h"
#include "pga2320.h"
#include "ad9833.h"

#include <string.h>

uint8_t wavetable_array[3][WAVETABLE_SIZE];

uint16_t curr_buf_pos;
uint16_t curr_read_buf_pos;
uint32_t curr_dump_pos;
uint8_t new_tick;

uint8_t chan_base_addr[20];

uint8_t curr_command;
uint8_t curr_chan;

uint32_t dummy;

extern Program_state_ccm state_ccm;
extern Program_state_ram state_ram;
extern uint8_t spi_rx_double_buf[];

extern uint8_t att_need_write;

TIM_TypeDef* pwm_timers[4] = { TIM3, TIM4, TIM8, TIM15 };
TIM_TypeDef* noise_clock_timer = TIM17;

USART_TypeDef* phase_reset_uarts[4] = { USART1, USART2, USART3, UART5 };
IRQn_Type phase_reset_interrupts[6] = { TIM20_UP_IRQn, 0, /*SysTick*/ USART1_IRQn, USART2_IRQn, USART3_IRQn, UART5_IRQn };

DMA_Channel_TypeDef* samp_chans_dma[3] = { DMA2_Channel3, DMA2_Channel4, DMA1_Channel6 };
DMA_Channel_TypeDef* wave_copy_chans_dma[3] = { DMA2_Channel1, DMA1_Channel7, DMA1_Channel1 };
TIM_TypeDef* samp_chans_timers[3] = { TIM6, TIM7, TIM16 };
IRQn_Type samp_chans_IRQ[3] = { DMA2_Channel3_IRQn, DMA2_Channel4_IRQn, DMA1_Channel6_IRQn };

__attribute__((section (".ccmram")))
void DMA2_Channel3_IRQHandler()
{
	DMA2->IFCR = DMA_IFCR_CTCIF3;
	DMA2_Channel3->CCR &= ~DMA_CCR_EN; //stop DMA
	TIM6->CR1 &= ~TIM_CR1_CEN;

	Sample_state* ss = &state_ram.dac[0];

	ss->curr_pos += ss->curr_portion_size;

	if(ss->curr_pos < ss->length)
	{
		DMA2_Channel3->CMAR = (ss->in_ram ? (uint32_t)&sample_mem_ram[0] : BASE_ADDR_FLASH) + ss->start_offset + ss->curr_pos;
		DMA2_Channel3->CNDTR = my_min(0xffff, ss->length - ss->curr_pos);
		ss->curr_portion_size = my_min(0xffff, ss->length - ss->curr_pos);

		DMA2_Channel3->CCR |= DMA_CCR_EN;
		TIM6->CR1 = TIM_CR1_CEN;

		return;
	}

	if(ss->curr_pos == ss->length && ss->loop)
	{
		ss->curr_pos = ss->loop_point;
		DMA2_Channel3->CMAR = (ss->in_ram ? (uint32_t)&sample_mem_ram[0] : BASE_ADDR_FLASH) + ss->start_offset + ss->loop_point;
		DMA2_Channel3->CNDTR = my_min(0xffff, ss->length - ss->curr_pos);
		ss->curr_portion_size = my_min(0xffff, ss->length - ss->curr_pos);

		DMA2_Channel3->CCR |= DMA_CCR_EN;
		TIM6->CR1 = TIM_CR1_CEN;

		return;
	}
}

__attribute__((section (".ccmram")))
void DMA2_Channel4_IRQHandler()
{
	DMA2->IFCR = DMA_IFCR_CTCIF4;
	DMA2_Channel4->CCR &= ~DMA_CCR_EN; //stop DMA
	TIM7->CR1 &= ~TIM_CR1_CEN;

	Sample_state* ss = &state_ram.dac[1];

	ss->curr_pos += ss->curr_portion_size;

	if(ss->curr_pos < ss->length)
	{
		DMA2_Channel4->CMAR = (ss->in_ram ? (uint32_t)&sample_mem_ram[0] : BASE_ADDR_FLASH) + ss->start_offset + ss->curr_pos;
		DMA2_Channel4->CNDTR = my_min(0xffff, ss->length - ss->curr_pos);
		ss->curr_portion_size = my_min(0xffff, ss->length - ss->curr_pos);

		DMA2_Channel4->CCR |= DMA_CCR_EN;
		TIM7->CR1 = TIM_CR1_CEN;

		return;
	}

	if(ss->curr_pos == ss->length && ss->loop)
	{
		ss->curr_pos = ss->loop_point;
		DMA2_Channel4->CMAR = (ss->in_ram ? (uint32_t)&sample_mem_ram[0] : BASE_ADDR_FLASH) + ss->start_offset + ss->loop_point;
		DMA2_Channel4->CNDTR = my_min(0xffff, ss->length - ss->curr_pos);
		ss->curr_portion_size = my_min(0xffff, ss->length - ss->curr_pos);

		DMA2_Channel4->CCR |= DMA_CCR_EN;
		TIM7->CR1 = TIM_CR1_CEN;

		return;
	}
}

__attribute__((section (".ccmram")))
void DMA1_Channel6_IRQHandler()
{
	DMA1->IFCR = DMA_IFCR_CTCIF6;
	DMA1_Channel6->CCR &= ~DMA_CCR_EN; //stop DMA
	TIM16->CR1 &= ~TIM_CR1_CEN;

	Sample_state* ss = &state_ram.dac[2];

	ss->curr_pos += ss->curr_portion_size;

	if(ss->curr_pos < ss->length)
	{
		DMA1_Channel6->CMAR = (ss->in_ram ? (uint32_t)&sample_mem_ram[0] : BASE_ADDR_FLASH) + ss->start_offset + ss->curr_pos;
		DMA1_Channel6->CNDTR = my_min(0xffff, ss->length - ss->curr_pos);
		ss->curr_portion_size = my_min(0xffff, ss->length - ss->curr_pos);

		DMA1_Channel6->CCR |= DMA_CCR_EN;
		TIM16->CR1 = TIM_CR1_CEN;

		return;
	}

	if(ss->curr_pos == ss->length && ss->loop)
	{
		ss->curr_pos = ss->loop_point;
		DMA1_Channel6->CMAR = (ss->in_ram ? (uint32_t)&sample_mem_ram[0] : BASE_ADDR_FLASH) + ss->start_offset + ss->loop_point;
		DMA1_Channel6->CNDTR = my_min(0xffff, ss->length - ss->curr_pos);
		ss->curr_portion_size = my_min(0xffff, ss->length - ss->curr_pos);

		DMA1_Channel6->CCR |= DMA_CCR_EN;
		TIM16->CR1 = TIM_CR1_CEN;

		return;
	}
}

__attribute__((section (".ccmram")))
void TIM2_IRQHandler()
{
	if(TIM2->SR & TIM_SR_UIF)
	{
		TIM2->SR &= ~TIM_SR_UIF;
		new_tick = 1;
	}
}

__attribute__((section (".ccmram")))
void load_noise_lfsr()
{
	Noise_state* noise = &state_ram.noise;

	//switch clock to GPIO mode
	GPIOB->MODER &= ~GPIO_MODER_MODER7;
	GPIOB->MODER |= GPIO_MODER_MODER7_0; //GPIO output

	if(noise->clock_source == 0)
	{
		NOISE_CLOCK_EXTERNAL
	}

	SCK_NOISE_HIGH

	CS_NOISE_LOW

	for(int i = 0; i < 23; i++)
	{
		if(noise->lfsr & (1 << i))
		{
			DATA_NOISE_HIGH
			SCK_NOISE_LOW
		}
		else
		{
			DATA_NOISE_LOW
			SCK_NOISE_LOW
		}

		asm("nop");
		asm("nop");
		asm("nop");
		asm("nop");
		asm("nop");
		asm("nop");
		asm("nop");
		asm("nop");
		asm("nop");
		asm("nop");
		asm("nop");
		asm("nop");
		asm("nop");
		asm("nop");
		asm("nop");
		asm("nop");
		asm("nop");
		asm("nop");
		asm("nop");
		asm("nop");
		asm("nop");
		asm("nop");
		asm("nop");
		asm("nop");
		asm("nop");
		asm("nop");
		asm("nop");

		SCK_NOISE_HIGH

		asm("nop");
		asm("nop");
		asm("nop");
		asm("nop");
		asm("nop");
		asm("nop");
		asm("nop");
		asm("nop");
		asm("nop");
		asm("nop");
		asm("nop");
		asm("nop");
		asm("nop");
		asm("nop");
		asm("nop");
	}

	CS_NOISE_HIGH
	DATA_NOISE_LOW

	if(noise->clock_source == 0)
	{
		NOISE_CLOCK_INTERNAL
	}

	GPIOB->MODER &= ~GPIO_MODER_MODER7;
	GPIOB->MODER |= GPIO_MODER_MODER7_1; //altfunc output (clock from timer)
}
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

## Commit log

2024-09-24 connection successful message + add resistor to filter feedback loop
    [board.kicad_sch]
2024-09-24 add noise clock source and mute function control
    [board.kicad_sch]
2024-09-25 fuck it, I ordered 4 2-ch attenuators so let there be DAC volume control!
    [board.kicad_sch]
2024-09-25 free uart pins
    [board.kicad_sch]
2024-09-27 added 1 more resistor to filter feedback, added +5v to remaining screw terminal, connected L & R audio channels for 3.5 mm jack
    [board.kicad_sch]
2024-09-28 reassign noise pins so that noise clock and noise data in are on the same GPIO port
    [board.kicad_sch]
2024-09-30 placed components
    [board.kicad_pcb]
2024-09-30 add Ux reference to boards and place components again...
    [board.kicad_pcb]
2024-09-30 horrible attempt at placing components
    [board.kicad_pcb]
2024-09-30 add caps on power lines, start tracing
    [board.kicad_pcb, board.kicad_sch]
2024-09-30 traced (changed some CS and mux select pins to make tracing easier)
    Dude that's horrible PCB...
    [board.kicad_pcb, board.kicad_sch]
2024-09-30 optimize board or idk
    [board.kicad_pcb]
2024-09-30 temporary gerbers
    [board-B_Cu.gbr, board-B_Mask.gbr, board-B_Paste.gbr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]
2024-10-01 attempt at tracing v2
    [board.kicad_pcb, board.kicad_sch]
2024-10-01 W I D E
    [board.kicad_pcb]
2024-10-01 more tracing...
    [board.kicad_pcb]
2024-10-01 more tracing tweaks
    [board.kicad_pcb]
2024-10-02 freeze timers in debug...
2024-10-03 new opamp, timers init
    [board.kicad_pcb, board.kicad_sch]
2024-10-05 more board rework, UART & SPI init
    [board.kicad_pcb, board.kicad_sch]
2024-10-09 add РПЗ template
    [board.kicad_pcb]
2024-10-09 added DMA init
    [board.kicad_pcb, board.kicad_sch]
2024-10-10 finish functional schematic?
2024-10-10 -Os compilation flag, add one more DMA channel for noise chip LFSR load
    [playback.c]
2024-10-11 add test file, add template data loading through UART
2024-10-11 uncomment timer init
2024-10-12 added separate connector for UART
    [board.kicad_pcb, board.kicad_sch]
2024-10-12 write external Flash reset commands and request ID, init GPIO, done with initial comms establishment packet
    [board.kicad_sch]
2024-10-13 added UART commands decode and internal flash erase and write functions, wrote down state
2024-10-15 add clocks enable for ADCs and UART4, change course project theme
    May later be used as timers
2024-10-16 PGA2320 driver, send only relative packet address, implement actual "task" to write into external flash, send response packet after writing data,
    Also in pc program send only relative data address (without flash or RAM array start offset)
2024-10-26 fix uart comms, place interrupt handlers in ccmram, AD9833 works
    [board_sem_edits.kicad_pcb, board_unfinished.kicad_pcb]
2024-10-26 place interrupt vector table to CCMRAM
2024-10-26 spi is 4 bytes late on receive due to FIFO...
    also test wavetable working with DAC
2024-10-27 spi flash works! read-erase-write
2024-10-27 fix sending external Flash chip UID
    [external_flash.c, main.cpp, uart.c]
2024-10-27 test both DAC channels with tri and noise gen
    2nd channel saturates at around 90% voltage, why?...
    [playback.c]
2024-10-27 play samples from internal flash, longer than 65535 steps, with custom loop point
2024-11-01 hopefully final PCB
    [board.kicad_sch, board_template_v3.kicad_pcb, board_v3_modules_traced.kicad_pcb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]
2024-11-03 crapsynth works with dac channels lmao
    [board.kicad_pcb]
2024-11-03 a couple of fixes
    [playback.c]
2024-11-03 skip nops more efficiently
    [playback.c]
2024-11-04 make DMA-copying wavetables work
2024-11-04 last minute addition (PWM DAC lmao), gerber files,
    [board-B_Cu.gbr, board-B_Mask.gbr, board-B_Paste.gbr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]
2024-11-09 fix wavtebles reading via DMA, now you can pad waves at 8k pages instead of 4k, thus file/data size is reduced
    [playback.c]
2024-11-10 Try to code FPGA SPI differently (still doesn't want to compile and work)
2024-11-22 attenuators work, DDS works again, DDS/PWM switch works, tested on real board which I finally soldered together
    [board.kicad_sch]
2024-11-23 Remove RTC, make all channels work on real device except 4th DDS/PWM (needs a wire to be soldered) and phase reset timers
    [ad9833.c, clocks_interrupts.c]
2024-11-24 Bigger data blocks, 2MBauds, phase reset timers commands
    Only two timers and 1 USART work as phase reset timers properly... others do some weird shit
    [external_flash.c, main.cpp, pga2320.c]
2024-11-29 a version that kinda works?
    [board_sem_edits.kicad_pcb, board_template_v3.kicad_pcb, board_unfinished.kicad_pcb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]
2024-12-03 lmao why I deleted all this. Anyway return some files, clean up the code, hopefully final version of the report etc.
    Also add potential muting ability to the PWM DAC chan
2024-12-04 phase reset for PWM too
    [playback.c]
2024-12-06 awful hack to make samples play properly
2024-12-13 fix resetting uart timers
    [playback.c]
